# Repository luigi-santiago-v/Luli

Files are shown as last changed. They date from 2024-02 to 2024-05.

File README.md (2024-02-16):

# Luli Hydroponics

## Project Overview
This project aims to create a user-friendly, data-driven, and internet-connected hydroponics system. Targeting food deserts, it offers a solution for accessible nutritious food through a smart home appliance. The system integrates temperature/humidity, light intensity, and water pH sensors, along with UV lighting, a water reservoir, a pump, and a microcontroller into a single appliance. It provides real-time plant health and nutrient data, enhanced by a community-driven web application for sharing insights and tips.

## Key Features

- Comprehensive sensor suite for real-time monitoring
- UV lighting and water management for optimal plant growth
- Community web application for knowledge and tips exchange
  - Python Flask + MongoDB backend
- Designed with food deserts and local community reliance in mind
- **Budget:** $500
- **Duration:** 9 months

## Goals
Develop an open-source hydroponic system to enable community-driven, urban agriculture, addressing the challenge of food deserts and their impact on academic performance. The project focuses on simplifying the hydroponics process for beginners, providing a robust system for easy monitoring and maintenance, and fostering community engagement to sustain interest and success in hydroponic gardening.

## Milestones
- Research, design, and component sourcing
- System assembly and testing
- Creation of a functioning prototype from OSB featuring integrated control and monitoring systems
- Demonstration of prototype efficacy with basic crop growth

## Problem Addressed
Tackles the challenges faced by urban growers, including knowledge barriers and the need for continuous system maintenance. Aims to motivate and support users from construction through to the ongoing cultivation process, making hydroponic gardening accessible and engaging.

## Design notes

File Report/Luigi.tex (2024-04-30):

\documentclass[12pt]{article} % Set font size to 12pt
\usepackage[T1]{fontenc} % For setting T1 encoding instead of OT1, typewriter style quotation marks
\usepackage{graphicx} % For including images
\usepackage{float} % For figure placement
\usepackage{titlesec} % For customizing section titles

\usepackage{tocbibind} % For adding the table of contents to the table of contents
\usepackage[toc,page]{appendix} % For adding appendices
\usepackage{url} % For adding URLs in the bibliography
\usepackage{amsmath} % For IPC 2221 Formula
\usepackage{pdfpages} % To include PDFs
\usepackage{listings} % For code formatting
\usepackage{geometry} % For setting page margins
\geometry{a4paper, margin=1in} % Set page margins to 1 inch
\usepackage{parskip}
\usepackage{siunitx}
\usepackage{subcaption} % For subfigures
\usepackage{pdfpages}

\usepackage{listings} % For code formatting
\lstnewenvironment{pythoncode}[1][]
{
    \lstset{
        language=Python,
        basicstyle=\small\ttfamily,
        keywordstyle=\color{blue},
        stringstyle=\color{orange},
        commentstyle=\color{gray},
        numbers=left,
        numberstyle=\tiny,
        numbersep=5pt,
        showstringspaces=false,
        breaklines=true,
        frame=single,
        captionpos=b,
        #1
    }
}
{} % This empty {} has to be there otherwise there's an error

\usepackage{listings} % For code formatting
\lstnewenvironment{htmlcode}[1][]
{
    \lstset{
        language=HTML,
        basicstyle=\small\ttfamily,
        keywordstyle=\color{blue},
        stringstyle=\color{red}, % Changed to red for HTML attributes
        commentstyle=\color{green}, % Changed to green for HTML comments
        numbers=left,
        numberstyle=\tiny,
        numbersep=5pt,
        showstringspaces=false,
        breaklines=true,
        frame=single,
        captionpos=b,
        #1
    }
}
{} % This empty {} has to be there otherwise there's an error

\begin{document}

\widowpenalty=10000
\clubpenalty=10000

\title{Luli Smart Cultivation:A Socially-Connect IoT Hydroponics Solution}

\begin{titlepage}
    \centering
    \vspace*{\stretch{1}}
    {\Large\bfseries SENIOR DESIGN PROJECT\par}
    \vspace{1.5cm}
    {\Large ECE 186B\par}
    \vspace{1.5cm}
    {\Large\bfseries Luli Smart Cultivation: A Socially-Connect IoT Hydroponics Solution\par}
    \vspace{3cm}
    {\large California State University, Fresno\par}
    {\large Lyles College of Engineering\par}
    {\large Electrical and Computer Engineering Department\par}
    \vspace{2cm}
    {\large Dr. Gregory Kriehn\par}
    {\large Professor Roger Moore\par}
    \vspace{2cm}
    {\large BY\par}
    \vspace{1cm}
    {\large Liam Goss\par}
    {\large Luigi Santiago-Villa\par}
    \vspace{\stretch{2}}
\end{titlepage}

% Table of Contents
\tableofcontents
\newpage

% List of Figures
\listoffigures
\newpage

\begin{abstract}
The issue of scaling global agricultural techniques is an ever-evolving problem as we consider notable concerns, such as renewable energy, global food security, loss of natural habitats, and soil degradation. The Luli Hydroponic System provides an automated IoT solution that leverages the ubiquitous nature of social networks to create a community of horticulturalists supported by a democratized collection of data. Furthermore, the system provides the urban agriculturalist with a user friendly and data rich experience that aims to alleviate the barriers to entry, most notably, the high learning curve and initial investment. To accomplish this task, the project incorporates a Raspberry Pi Pico W to serve as the central processing unit of the system. Although small and limited with onboard memory, the Pico is a cost effective component that specializes in optimized software and generous I/O port interfaces that can leverage cloud computing technology. The hydroponic device is compact and equipped with sensors that gather data critical for healthy plant growth. The design of the hydroponic system discreetly houses four DHT-22 temperature and humidity sensors that give an accurate description of the environment. Furthermore, a light sensor, which is nestled closely to the growing trays, will give the user a real time measurement of the 12V 60 watt grow lights attached to the roof. The project is constructed within a \textdollar 500 budget under a 9 month time frame. 
\end{abstract}

\section*{Overview}
The Luli system is an automated hydroponic setup that employs ebb and flow techniques and integrates IoT-capable components to deliver a user-friendly growing experience. The physical design of the device is compact standing at just 31in with a base measuring 24 x 24 in. The structure is lightweight due to the use of oriented strand board and the roof is supported with 1/4 in PVC pipes. The PVC supports allowed us to discreetly route wires to the array of LED growing lights attached to the roof, as well as the sensors located adjacent to the growing containers. The system takes UV, humidity, temperature, and pH measurements to provide a real time account of the environment in which the plants are growing. An ultrasonic sensor in the reservoir tank, which is located under the growing container, will provide an accurate measurement of the solution level. The data collected will be displayed onto a 2.4in OLED screen attached to the front of the system.

In addition, the user can sign into their Luli Hydroponic account to track the device’s data output through the use of the Luli web portal. The sensors send data to the MangoDB database, and the Flask oriented back-end serves a dynamic front-end to the user. From the HTML based front-end, users can adjust the settings of their device and connect with other users to build a network of urban horticulturalists. Furthermore, users are able to share setting profiles and communicate with one another to create a democratized collection of horticulture techniques. Communications are facilitated through a forum page that gives users a space to share updates on the state of their plants and share images of their progress. The online platform is designed to be engaging and functional, whilst maintaining a user friendly environment. 

\pagebreak

The hydroponic system was developed and constructed over the span of 9 months. The initial project budget was set at \textdollar 500. At the point of completion the budget spent was just under budget \textdollar 426. The goal of the project is to bring attention to the prevalence of the food deserts. By building a community of open-source devices, we believe in time that the device will bring nutritional options to those who live in urban environments where nutritional needs are not always met.

\section {Circuit Design and Testing}

\begin{figure}[H]
  \centering
  
  \caption{Circuit Design}
  \label{fig:Schematic}
\end{figure}

The heart of the circuit is the Raspberry Pi Pico W. This microcontroller is a relatively inexpensive unit that gives the user 40 general-purpose input/output pins. At the bottom left of the schematic we can see the array of 60W growing light LEDs. The LED strips require 12V and 3A to operate correctly. This is far above what the Pico can provide and a 12V AC-to-DC power supply unit was added to the design to provide power to the LED arrays and water pump. The rest of the sensors only require a max of 5V and at the center of Figure \ref{fig:Schematic}, we can see a 12V to 5V buck converter. The buck converter provides the bucked down voltage to the sensors of the hydroponics system such as the DHT-22 humidity and temperature sensor, HCSR04 ultrasonic sensor, LTR-390UV-01 light sensor, and PH-4502C analog pH sensor. 

\subsection{Power Supply Testing}

The system has two voltage requirements that the power supply provides. The Raspberry Pi Pico W and sensors can only handle up to 5V. The water pump and LEDs required a higher voltage of 12V. To provide both voltages from a single outlet, a BMOUO 12V AC-to-DC power supply and DORHEA C120503 12V to 5V DC converter are used. Further more, a FILSHU 10A 250V Power Socket Inlet Switch with a Detachable 3-Prong Power Cord connects the power supply to the 120V wall outlet. As shown in Figure \ref{fig:PSU test Circuit}, the smaller buck converter was attached to the power supply. 

\begin{figure}[H]
  \centering
  
  \caption{Power Supply Test Circuit}
  \label{fig:PSU test Circuit}
\end{figure}

With the components all wired, the power cord was plugged into a power outlet, and the 12V power supply was turned on. A green light on the power supply turned on indicating that the unit has not experienced a short or failure. When we measured the output voltage, we got a reading of 12V. This confirmed the operation of the power supply. The multi-meter was then used on the Buck Converter and a steady measurement of 4.9V was observed. This final measurement showed that the entire power supply circuit was functional and the other components were ready to be powered. 

\subsection{DHT Sensor Testing}

\begin{figure}[H]
  \centering
  
  \caption{DHT-22 Test Circuit}
  \label{fig:DHT-22 Test Circuit}
\end{figure}

The Luli Hydroponic System is a host to 5 seamlessly integrated sensors. Each sensor plays a critical role in successful hydroponics, and after acquisition of the components, their functionality and accuracy was tested. The DHT-11 sensor was chosen due to its dual utility as a humidity and temperature sensor. This reduces the number of GIO pins needed from the Pico microcontroller. According to the datasheet provided by Mouser electronics \cite{ref_dht}, the DHT-11 sensor can measure temperatures within an accuracy of $\pm 2^\circ\text{C}$. Similarly, humidity measurements have an accuracy within $\pm 5 \%$. In order to test functionality, the sensor’s VDD pin is connected to the VBUS of the microcontroller. The sensor’s data prong is linked to the Pico’s GIO 1 pin, in conjunction with a $5 k\Omega$ pull-up resistor. As shown in Figure \ref{fig:DHT-22 Test Circuit}, the test circuit is completed by connecting the sensor and the microcontroller’s ground together. In order to program the microcontroller, the coding IDE Thonny was used and the software was developed in microPython. The test first defines the data pins connected to the DHT-11 sensors. A while loop is used to continuously poll the sensors until a successful measurement is conducted and the output is printed. A short delay of 3 seconds is provided inline with the sensor’s minimum measurement rate.

\begin{figure}[H]
  \centering
  
  \caption{DHT-11 Failed Test}
  \label{fig:DHT-22 Accuracy test}
\end{figure}

The First round of testing on the DHT-11 proved unsuccessful, and as shown in Figure \ref{fig:DHT-22 Accuracy test}, a Timeout error was encountered when attempting to gather measurements. To determine the source of the fault, it was important to test the remaining supply of DHT-11 sensors with the test circuit before any modifications to the code or circuit were made. After swapping each DHT-11 sensor, it was discovered that each behaved in the same manner and the timeout error was not resolved. The timeout error is typically caused when a sensor fails to respond with data within an expected period of time. Therefore, the delay within the test code was reduced to the minimum delay of 1s, which is specified in the DHT-11 datasheet, and then adjusted far longer than needed. Neither change produced a successful result and therefore attention was returned again to the hardware. 

In an attempt to further pinpoint the cause of the issue, it was then assumed that the sensors used could in fact be malfunctioning. To test this theory, an alteration to the test circuit was made by replacing the sensor with its more reliable version, the DHT-22. After swapping the sensors in the test circuit, the code was run in Thonny and an attempt to gather environmental measurements was attempted. The exchange in sensors proved to be successful and a temperature reading was returned. Depicted in Figure \ref{fig:DHT-22 Succesful test}, the DHT-22 sensors returned humidity and temperature data after a series of readings and it was therefore decided to alter the original design of the system to include DHT-22 sensors instead of the DHT-11 sensors. 

\begin{figure}[H]
  \centering
  
  \caption{DHT-22 Successful Readings}
  \label{fig:DHT-22 Succesful test}
\end{figure}

\subsection{OLED Screen}

The screen chosen for our design is the 2.42in OLED LCD display produced by DWEII Electronics. In order to test this screen, we first wired the component to the Raspberry Pi Pico W. The VCC pin on the OLED display was connected to the VBUS of the microcontroller and draws a voltage of 3.3v. When choosing pins on the Raspberry Pi Pico, it was important to note which protocols were supported, and for this test, pins 10-15 were chosen since they support SPI communication. GIO pin 10 was defined as the system clock output and set to a baud rate of 1MHz. The screen communicates with the Pico using SPI communication and the screen acts as the slave unit. To interface the communication between devices pin 11 on the Pico was used as the MOSI port. The reset pin of the screen was connected to GIO pin 14, and pin 13 was connected to the CS pin of the screen. The test circuit was completed by connecting the ground of the screen to the Pico’s ground pin. To drive the circuit, the code, shown in appendix , was written to display a simple “Successful” message to the screen.

\begin{figure}[H]
  \centering
  
  \caption{OLED Display Test Circuit}
  \label{fig:OLED Test}
\end{figure}

The first attempt to drive the screen was unsuccessful. When the code was run, the screen flickered for a brief moment before it turned off and remained black. Since we observed a change in the screen, it was likely that a wire was incorrectly placed or a component was not fully driven into the breadboard. First we ensured that the connections between the components were secured and correct. After checking connections, the board yet again failed to remain on. Next we checked the headers that were soldered onto the OLED screen. Under closer examination, it was discovered that a pin was not fully soldered. The joint had formed a cold joint, and when moved, we observed that there was space between the cold joint and the VCC pin of the screen. Careful attention was given to each header pin to ensure that no other pins were loose, and the headers were re-soldered on with better connections. Once that error was fixed, the program was run, and on the third attempt, the screen turned on and the success message was displayed. Figure \ref{fig:OLED Success} shows the Pico printing the message to the screen and confirms that the unit is functional. 

\begin{figure}[H]
  \centering
  
  \caption{Successful OlED Screen Test}
  \label{fig:OLED Success}
\end{figure}

\subsection{Water Pump}

The water pump chosen for the Luli Hydroponic System was the Gikfun Mini 12v Diaphragm Pump. According to the pump's listing, the unit can take anywhere from 6-12V depending on the speed and power desired from the pump. To test this, the pump was first connected to the output of the 12V power supply. Two water cups were used to provide the pump with a small amount of water from which to draw from. Since the pump will need to pump water up to the grow baskets, the water cups were placed below the pumps to test whether the pump was strong enough to draw water vertically. 

\begin{figure}[H]
  \centering
  
  \caption{Failed Pump Test}
  \label{fig:Pump Fail}
\end{figure}

\pagebreak

When the power was turned on, the pump immediately whirled into operation. Unfortunately, there was a critical error in manner in which the pump was tested. The team did not anticipate the unit moving when turned on. The moment the pump begin to pump water, it twisted due to the rotating components in the pump and fell into one of the cups of water. This caused irreparable damage to the pump. After letting the pump dry over the course of a few days, it was retested and its operation was damaged. The strong flow we initially saw slowed down to a small trickle, and the unit struggled to pull water. In this damaged state the pump would not supply the power necessary to flood three growing trays. Therefore the unit was replaced with a CrocSee 12V DC Diaphragm Pump. During the test of the replacement pump, the pump was taped down to the table to ensure that the same mistake was not repeated. This unit can only be powered with 12V \cite{ref_crocsee} and it was placed into the test circuit. This replacement pump worked exactly as expected and was capable of filling a growing basket. Therefore, the CrocSee diaphragm pump served as our water pumping device for the 3 growing baskets. Vinyl tubing was attached to the intake and outtake ports on the pump. These tubes lead to a cross junction that splits the flow into three vinyl tubes. When the unit was tested with complete vinyl tubing system, it was discovered that the flow of water tended to favor the middle tub. To remedy this issue, the middle tube was replaced with a smaller diameter tube. This corrected the pressure and the three tubes received equal flows of water.   

\subsection{Ultra-Sonic Sensor HC-SR04}

\begin{figure}[H]
  \centering
  
  \caption{Luli Hydroponic System Housing}
  \label{fig:HCSR04 Test Circuit}
\end{figure}

\pagebreak

The HC-SR04 ultrasonic sensor was placed on top of the reservoir tank and takes measurements of the solution’s level. The sensor is accurate within 3mm and has a practical range between 2cm and 80cm \cite{ref_hcsr04}. Two tests were conducted on this sensor. First the unit was tested for functionality. In order to accomplish this, the ultrasonic sensor was interfaced to the Pico by first connecting the VCC pin to the VBUS output of the Raspberry Pi Pico. This provides the unit with the 5V necessary to drive it. The trigger pin was connected to GIO pin 5 and the echo pin was interfaced with GIO pin 6. The microPython program activates the trig pin for 10 microseconds and the echo pin receives the returning ultrasonic pulse, which is transmitted to the Pico for analysis and conversion. Once the data from the ultrasonic pulse is received by the microcontroller, the data must be converted.

\begin{figure}[H]
  \centering
  
  \caption{HRSR04 Accuracy Testing}
  \label{fig:accuracy test}
\end{figure}

In order to confirm that the sensor is reading data correctly, a function was written that first sends a logical 1 value to the trigger pin, and if successful, the transmitter will emit an ultrasonic pulse that the receiver will detect. The echo pin will go high at the end of the transmission and remain high until an ultrasonic pulse is detected by the receiver. Once the function detects the low signal from the echo pin, the difference between the signalOn and signalOff is calculated to determine the period, which is measured in \si{\micro\second}, that the sonic signal took to travel between two points. This time period is then converted by multiplying by the distance sound travels in a micro second:
\begin{equation}
\text{Distance} = \frac{\text{Time Duration} \times 0.0343}{2}
\end{equation}

\begin{figure}[H]
  \centering
  
  \caption{HCSR04 Measurement Results}
  \label{fig:HCSR04 Accuracy Test}
\end{figure}

\pagebreak

When the test code was run, the unit appeared to be operational and a series of measurements were output to the terminal. This confirms that the unit is at least functional, and sends a signal when triggered. In order to test that the data printed was accurate, an object was placed 5.0cm apart from the sensor. A measurement within 3mm would be considered accurate and within the manufacturer specifications \cite{ref_hcsr04}. After running the test code a second time, it was determined that the measurements were sufficiently accurate with a small spike in inaccuracy in the initial rounds of the measurement loop. Overall all the measurements, shown in Figure \ref{fig:HCSR04 Accuracy Test}, were within 3-5mm of the sensor. This is more than acceptable when we consider that the distance of 5.0cm was measured from the front of the receiver’s housing and the actual hardware that detects the echo pulse recedes an unknown distance within the housing. 

\subsection{LED Strips}

\begin{figure}[H]
  \centering
  
  \caption{Arrangment of LEDs}
  \label{fig:LEDarray}
\end{figure}

For growing plants, a set of 60W 12V full spectrum growing LED lights were purchased. Before testing the lights, they were first prepared to be applied to the roof of the enclosure. The LED strips were cut into 12in long strips and 18 gauge wires were soldered on to each to connected them to the power supply. The LED strips have an adhesive back and were attached to the OSB roof panel in the configuration shown in Figure \ref{fig:LEDarray}. A series of eight strips were used with four backup strips applied in case of failure during testing. First a single strip was tested by attaching the LEDs to a power supply device and left on for 10 minutes. Once the functionality of the LEDs was confirmed, the second test was conducted to test the LEDs wired in parallel and the terminal blocks purchased for parallel power supply. 

\begin{figure}[H]
  \centering
  
  \caption{Operation of Growing Lights Compared To Decorative LEDs}
  \label{fig:Comparison}
\end{figure}

After turning on the power supply, no issues were observed. The lights were bright and intense. They gave a soft warmth but did not heat up considerably over the period of 10 minutes. This gave the team confidence that, over a long period, the LEDs will not overheat and loosen the adhesive gluing them to the roof. In Figure \ref{fig:Comparison}, we see a comparison of grow lights to a set of decorative LEDs. In the image, we can see the difference in intensity. With the confirmation of the single strip of LEDs, the final test was conducted on a fully wired array of eight LEDs. The terminal blocks were supplied with 12V and the array immediately lit up. No dead lights were observed, and after a period of ten minutes, it was concluded that the arrays were ready to add to the project. 

\begin{figure}[H]
  \centering
  
  \caption{Successful Parallel Wiring of LED Array}
  \label{fig:Light Array On}
\end{figure}

\section{Physical Enclosure Design and Implementation}

\begin{figure}[H]
  \centering
  
  \caption{Luli Hydroponic System Enclosure Schematic}
  \label{fig: housing schematic}
\end{figure}

The housing of the Luli Hydroponic System is designed to be compact with LEDs and environmental sensors housed in the roof of the enclosure. The body of the system is constructed using an engineered wood material called oriented strand board. This material is often used in large scale constructions for its load bearing properties, due to the lack of internal voids and various orientations of the compressed wood strips. The material is nearly water tight, and the outermost layer requires the application of a water sealant. After cutting the boards to size, three layers of polycrylic sealer were applied to prevent moisture from warping the wood. The housing is split into three individual parts. The design of the bottom enclosure is split into two sections. 

\begin{figure}[H]
  \centering
  
  \caption{Buttom Section with Seperate Compartments}
  \label{fig:bottom compartment}
\end{figure}

The largest of the two sections will hold the reservoir, diaphragm pump, HC-SR04 ultrasonic sensor, and pH pump. The reservoir chosen for this design is the 2 gallon Chaplin International Replacement tank. This tank can hold a substantial amount of fertilizer solutions in a low profile body that is 21.6 x 6 x 8.5in. The reservoir is typically used to mix industrial strength agricultural fertilizers, and this re-purposing would fit within the specifications of its original design. This guarantees that the tank can hold fertilizer materials without degrading due to the pH of the growing solutions. Next to the tank will sit the diaphragm pump with its wires running to the driver board located in the adjoining compartment.

\begin{figure}[H]
  \centering
  
  \caption{Middle Growing Compartement Before Drilling and Adding Growing Trays}
  \label{fig:mid Housing}
\end{figure}

The second compartment of the bottom enclosure is considerably more compact with a width of 6 inches. This is where the core of electronics will be housed. Most notably the power supply and Raspberry Pi Pico W. Special care was taken to ensure that the components would fit. For example, it was discovered that the power supply was too long to fit alongside the breadboard and printed circuit board. In order to save on horizontal space, it was concluded that the unit would need to be installed vertically. With this in consideration, the electronic hardware all fit within this section with the wire control from the various components serving as the final cause of concern.

\begin{figure}[H]
  \centering
  
  \caption{Wiring of The Enclosure with Bulkhead Ports Complete}
  \label{fig:top housing}
\end{figure}

The base was constructed with four 24x10in boards and a 24x24in floor. The OSB does not handle drilling very well and tends to fray when drilled into. Therefore, before any screw was driven into the board, an appropriate pilot hole was drilled. The edges of the boards are too small to drill into. As shown in Figure \ref{fig:bottom compartment}, a series of 2x2in furring strips were used to give the walls a surface to drill the separate panels together. This technique of drilling pilot holes proved to be very successful and no cracks were developed when connecting the sides together. To further ensure that a failure of the plumping or pump would not flood the electronic components, a ring of caulking was applied to the corners of all surfaces. The construction of the base was simple and no complications were encountered. 

\begin{figure}[H]
    \centering
    \begin{subfigure}[b]{0.5\textwidth}
        \centering
        
        \caption{Growing Tubs with 4in Grow Baskets}
        \label{fig:tubGrowbaskets}
    \end{subfigure}
    \begin{subfigure}[b]{0.45\textwidth}
        \centering
        
        \caption{Growing Tubs with Bulkhead Fittings}
        \label{fig:tubBulk}
    \end{subfigure}
    \caption{Growing Tubs}
    \label{fig:renderings}
\end{figure}

Just above the base, is the growing bed that contains the plant trays, base of the PVC roof supports, and ports for plumbing and electric wires. The growing bed was constructed using 5x24in OSB panels and 24x24in OSB floor. Four furring strips were used to give the panels a foundation to which the panels and floor can be attached to make a square growing tray. Once constructed, a series of holes were drilled into the middle compartment. The first of which were the 3/4in holes for routing piping from the bulkheads of the growing trays back to the solution reservoir. The three growing trays themselves are 6Qt 18x5x8in plastic tubs with a 3/4in hole drilled into the bottom. A PVC bulkhead was attached here to allow for draining of the hydroponics solutions. A pair of 4in holes, depicted in Figure \ref{fig:tubGrowbaskets}, were drilled to the top to hold the growing baskets. The baskets along with their piping system were installed with no issue. 

\begin{figure}[H]
  \centering
  
  \caption{Growing Compartment Completed with Wiring, Plumbing, and Roof Support}
  \label{fig:growingCompartment}
\end{figure}

\pagebreak

There are seven external components that require wiring back to the Pico and power supply. The LED array and DHT-22 sensors are placed the furthest and would need 18 gauge wires measuring at least 2-3ft. To freely allow these wires to run from the Raspberry Pi Pico W to the sensors, a 1/2in hole was drilled into the floor of the middle housing section and into the PVC leg cap. The wiring for the roof electronics was carefully feed through the middle compartment port and up the leg cap of the PVC pipe. A steel wire was used to grip the end of the electrical wires and pull it through sections of PVC. The DHT-22 sensors were placed at the corners of the roof and the three wires required for the sensor were pulled to each of the four corners. The power and ground wires were colored coded to a traditional black/red, whilst a blue wire was used to indicate a data line. The power wires for the sensors were attached together with zip ties and the data lines were managed in a similar fashion. A small 3/4in hole was drilled into a horizontal PVC pipe of the roof support to supply the LED array with power. 

\begin{figure}[H]
  \centering
  
  \caption{Completed Enclosure}
  \label{fig:Completed Project}
\end{figure}

\pagebreak

Placing all the electronic components within the enclosure was difficult work that required constant testing after each component was added to the Enclosure. The power supply was first added to the housing, with the 12V DC power supply screwed in vertically to save on space in the circuit section of the bottom enclosure. Furthermore, the PCB and bread board containing the Raspberry Pi Pico W and terminal connections were placed at the forefront of the circuit housing. The wires routed through the PVC pipes were connected to the appropriate terminals on the breadboard. After each collection of sensors were connected, their operations were tested to ensure that they were wired correctly before adding more components. A triangular enclosure was specifically built for the OLED LCD Screen. As shown in Figure \ref{fig:Completed Project} the LCD screen was attached to the front of the Luli System with the use of this enclosure. Before placing the reservoir into the larger compartment of the base, a series of holes were drilled into the top of the reservoir. The pH probe was placed in the deepest portion of the reservoir to ensure constant contact with the solution. The other holes were drilled to place the HCSR04 ultrasonic sensor on top of the tank. With these electronics in place, the reservoir was placed into the housing. The wires from these sensors where connected to the bread board and PCB concluding the housing construction and implementation. 

\section{Front-End Design And Development}

\begin{figure}[H]
  \centering
  
  \caption{Initial Sketch of The Web Portal}
  \label{fig: Portal Sketch}
\end{figure}

\pagebreak

When the Luli Hydroponic system is powered and connected to the internet, the user will interact with the device through the use of the Luli Web Portal. The notable hurdles to horticulturalists new to hydroponics is the high learning curve and constant monitoring of the plants. With this in mind, the design philosophy of the web application places emphasis on user friendly design with a minimalist layout. As shown in Figure \ref{fig: Portal Sketch}, the original sketch of the website gives the user a minimal navigation panel. The user would need to first sign in order to see the real time measurements in the bottom right corner of the sketch. The colors scheme was chosen to give the portal a retro appearance mixed with earthy colors.

\begin{figure}[H]
  \centering
  
  \caption{Create Account Portal}
  \label{fig: create account}
\end{figure}

The front-end was developed using HTML, CSS, and JavaScript, which adds dynamic elements to the static pages. The implementation of the portal is depicted in Figure \ref{fig: create account}, and some key changes were made to the original design. Users now have the option to view their friend's list, post to the cite forum, and adjust their system's settings. Most notably, the measurements were moved from the bottom right corner onto their own separate page. As shown in \ref{fig: plant page}, the plant page is neatly organized with the data presented clear and in a manner that is intuitive. The left panel presents the user with real time measurements served by the Flask supported back-end server. The container left of the measurements is a plant info panel that gives the user information about which plants are currently in the enclosure, important dates, and a field indicating which container holds the plant. 

\begin{figure}[H]
  \centering
  
  \caption{Plant Information Page}
  \label{fig: plant page}
\end{figure}

The settings page gives the user the ability to modify the default settings of their hydroponic system. From settings, the user can choose how often their plants get watered, the amount of water the plants receive, and the duration of the light cycles. Furthermore, users can adjust the plant info panel from this page to better reflect the plants present in their grow trays.

\begin{figure}[H]
  \centering
  
  \caption{Settings Control Panel}
  \label{fig: friends page}
\end{figure}

The social component of the Luli Hydroponic System is demonstrated in Figure \ref{fig: friends page}, where users can give updates about their plant through their about section. The Down arrow is a button where users can download each other settings, which is then applied to their system. Each time the settings page is updated, these friend settings are overwritten. The Luli website establishes a platform where users are able to freely connect, share growing techniques, and building communities with open access to nutritious choices. 

\begin{figure}[H]
  \centering
  
  \caption{Luli Website Friends Page}
  \label{fig: friends page}
\end{figure}

\section{Conclusion}

The Luli Hydroponic System provides a socially connected IoT device that excels in user accessibility. The system contains a network of sensors that give accurate readings of the plant's environment. Additionally, users have access to the Luli web portal where they can connect with other users to form a network of urban horticulturalists. The configuration of the Luli System can be edited from the settings page. From this portal, users can further share their system's settings to create a democratized center of hydroponic data. The system was constructed within a time frame of 9 months and remained well within the budget of \textdollar500. Over the course of this project, the team improved upon valuable skills critical in the engineering field. Through careful time management and task allocation, the project was completed by the projected timeline. The solving of complex problems was facilitated through communicative teamwork. 

\pagebreak

\appendix

\section{Software Appendix}

\begin{pythoncode}[caption={HCSR04 Ultrasonic Sensor Python Test Code}]
import machine
import utime
# Pin assignments
trig = machine.Pin(5, machine.Pin.OUT)
echo = machine.Pin(6, machine.Pin.IN)
def read_distance():
    # Ensure the trigger pin is low for a short time
    timeout = 10000  # timeout in microseconds
    trig.low()
    utime.sleep_us(5)

    # Send a 10us pulse to start the measurement
    trig.high()
    utime.sleep_us(10)
    trig.low()
    # Measure the length of the echo signal
    start_time = utime.ticks_us()
    while echo.value() == 0:
        if (utime.ticks_diff(utime.ticks_us(), start_time) > timeout):
            return None  # return None if no signal detected within the timeout
    signal_off = utime.ticks_us()
    start_time = utime.ticks_us()
    while echo.value() == 1:
        if (utime.ticks_diff(utime.ticks_us(), start_time) > timeout):
            return None  # return None if signal doesn't end within the timeout
    signal_on = utime.ticks_us()
    # Calculate the duration of the echo pulse
    time_passed = utime.ticks_diff(signal_on, signal_off)

    # Calculate distance in centimeters
    distance = (time_passed * 0.0343) / 2
    return distance
while True:
    distance = read_distance()
    if distance is not None and distance > 2:  # Check if distance is plausible
        print("Distance:", distance, "cm")
    else:
        print("Out of range or too close")
    utime.sleep(1)
\end{pythoncode}
\pagebreak
\begin{pythoncode}[caption={DHT-22 Sensor Test Code}]
import dht
from machine import Pin
import machine
import time

print("Starting DHT11.")
d0 = dht.DHT11(machine.Pin(16,Pin.IN,Pin.PULL_DOWN))

while True:
    print("Measuring.")
    
    retry = 0
    while retry < 3:
        try:
            d0.measure()
            break
        except:
            retry = retry + 1
            print(".", end = "")
   
    if retry < 3:
        print("Temperature: %3.1f °C" % d0.temperature())
        print("   Humidity: %3.1f %% RH" % d0.humidity())
    time.sleep(3)

\end{pythoncode}

\pagebreak

\begin{pythoncode}[caption={Main MicroPython Code}]
from machine import Pin, SPI
import ssd1306
import time
spiInit = SPI(1,baudrate=1000000,polarity=1,phase=1,bits=8,firstbit=machine.SPI.MSB,sck=machine.Pin(10),mosi=machine.Pin(11))

cs = Pin(13)   # chip select, some modules do not have a pin for this
dc = Pin(15)    # data/command
rst = Pin(14,Pin.OUT)   # reset

display = ssd1306.SSD1306_SPI(128, 64, spiInit, dc, rst, cs)
dataTest = 123
    
def printSenorData(ph,temp,light,humidity,solution):
    display.fill(0)
    display.hline(7,11,120,1)
    display.fill_rect(0,0,2,64,1)
    #display.text('Environment',6,0,1)
    display.text('pH: '       + str(ph) ,6,16,1)
    display.text('Temp: '     + str(temp),6,27,1)
    display.text('Light: '    + str(light),6,39,1)
    display.text('Humidity: ' + str(humidity),6,51,1)
    display.text('Tank: ' +  str(solution),6,0,1)    
    display.show()

def printPlantMenu():
    display.fill(0)
    display.hline(7,11,120,1)
    display.fill_rect(0,0,2,64,1)
    display.text('Plants',6,0,1)
    display.text('Plant: Spinach',6,16,1)
    display.text('Planted: 5/5/24',6,27,1)
    display.text('Harvest: 9/3/24',6,39,1)
    display.show()
menuSelect = 0;
prevHighlight = 0
display.poweron()
display.show()

while(True):
    printSenorData(dataTest,dataTest,dataTest,dataTest,dataTest)
    time.sleep(6)
    printPlantMenu()
    time.sleep(6)

\end{pythoncode}

\pagebreak
\begin{htmlcode}[caption={Control Panel Html}]

<!-- control_panel.html -->
<!DOCTYPE html>
<html lang="en">
<head>
<meta charset="UTF-8">
<title>Control Panel - LuLi Hydroponics</title>
<link href="{{ url_for('static', filename='style.css') }}" rel="stylesheet">
<script src="{{ url_for('static', filename='scripts/controlPanel.js') }}"></script>
</head>
<body>
<header>
    <img class="logo" src = "{{ url_for('static', filename='images/hydroponic.png')}}" alt = "hydroPlant"  width = 50 height =50 style = "float: left;" >   
    <img src = "{{ url_for('static', filename='images/luli_logo.png')}}" alt="Luli Hydroponics" width = 60 height= 60 style="float: left">
    
</header>
<nav class = "nav_list">
      
    <div class = "button" > 
       <a href="/" target=" _self"><img src = "{{ url_for('static', filename='images/user.png')}}" alt = "login" height= 50 width = 50></a>
       <label class="button_label"> Login </label> 
    </div>
    <div class = "button" > 
       <a href="/plants" target=" _self"> <img src = "{{ url_for('static', filename='images/pot.png')}}" alt = "plant" height= 50 width = 50> </a>
       <label class="button_label"> Plants </label> 
    </div>
    <div class = "button" > 
       <a href="/friends" target=" _self"> <img src = "{{ url_for('static', filename='images/friends.png')}}" alt = "plant" height= 50 width=50> </a>
       <label class="button_label"> Friends </label> 
    </div>
    <div class = "button" > 
       <a href="/forum" target=" _self"> <img src = "{{ url_for('static', filename='images/discussion.png')}}" alt = "plant" height= 50 width=50> </a>
       <label class="button_label"> Forum </label> 
    </div>
    <div class = "button" > 
       <a href="/settings" target=" _self"> <img src = "{{ url_for('static', filename='images/setting.png')}}" alt = "plant" height= 50 width=50> </a>
       <label class="button_label"> Settings </label> 
    </div>
       
   </nav>
<article>
    <div id="controls">
        <button onclick="sendCommand('motor', 'on')">Turn Motor On</button>
        <button onclick="sendCommand('motor', 'off')">Turn Motor Off</button>
        <button onclick="sendCommand('leds', 'on')">Turn LEDs On</button>
        <button onclick="sendCommand('leds', 'off')">Turn LEDs Off</button>
    </div>
</article>
<script>
    function sendCommand(device, action) {
        const data = { [device]: action };
        fetch(`/api/update_manual_override/{{ device_id }}`, {
            method: 'POST',
            headers: { 'Content-Type': 'application/json' },
            body: JSON.stringify(data)
        })
        .then(response => response.json())
        .then(data => console.log('Command sent:', data))
        .catch(error => console.error('Error sending command:', error));
    }
</script>
</body>
</html>
\end{htmlcode}

\pagebreak

\begin{htmlcode}[caption={Create Account HTML}]
<!DOCTYPE html>
<html lang = "en">
<head>
<meta charset = "UTF-8">
<title> LuLi Hydroponics </title>

<link href="style.css" 
      rel = "stylesheet">

</head>

<body>
 
   <header>
      <img class="logo" src = "images/hydroponic.png" alt = "hydroPlant"  width = 50 height =50 style = "float: left;" >   
      <img src = "images/luli_logo.png" alt="Luli Hydroponics" width = 60 height= 60 style="float: left">
      
   </header>

   <nav class = "nav_list">
      
    <div class = "button" > 
       <a href="/" target=" _self"><img src = "images/user.png" alt = "login" height= 50 width = 50></a>
       <label class="button_label"> Login </label> 
    </div>
    <div class = "button" > 
       <a href="/plants" target=" _self"> <img src = "images/pot.png" alt = "plant" height= 50 width = 50> </a>
       <label class="button_label"> Plants </label> 
    </div>
    <div class = "button" > 
       <a href="/friends" target=" _self"> <img src = "images/friends.png" alt = "plant" height= 50 width=50> </a>
       <label class="button_label"> Friends </label> 
    </div>
    <div class = "button" > 
       <a href="/forum" target=" _self"> <img src = "images/discussion.png" alt = "plant" height= 50 width=50> </a>
       <label class="button_label"> Forum </label> 
    </div>
    <div class = "button" > 
       <a href="/settings" target=" _self"> <img src = "images/setting.png" alt = "plant" height= 50 width=50> </a>
       <label class="button_label"> Settings </label> 
    </div>
       
   </nav>
     
<article>
      
      <div id = "createAccount" class="createAccount">
        <div class = "circleLogo">
            <div class = "logoFrontPage">
                <img src = "images/luli_logo.png" alt="Luli Hydroponics" width = 160 height= 160 style="float: center" >
            </div>

        </div>

        <form id="createAccountForm" class = "createAccountForm" action = "/create_account"  method = "POST" enctype="multipart/form-data">

            <div id = "welcomeMessage" class = "welcomeMessage">Welcome to Luli Hydroponics!</div>

            <div class="formGroup">  
               <label for="first-name">First Name:</label>
               <input type="text" id="first-name" name="first-name" required>
            </div>
            <div class="formGroup">
               <label for="last-name">Last Name:</label>
               <input type="text" id="last-name" name="last-name" required>
            </div>
            <div class="formGroup">
               <label for="username">Username:</label>
               <input type="text" id="username" name="username" required>
            </div>
            <div class="formGroup">
               <label for="password">Password:</label>
               <input type="password" id="password" name="password" required>
            </div>
            <div class="formGroup">  
               <label for="profile_pic">Profile Picture:</label>
               <input type="file" id="profile_pic" name="profile_pic" accept="image/jpeg, image/jpg">
            </div>
            <button type="submit" class = "createAccountButton">Create Account</button>
        </form>       

      </div>
</article> 
   
</body>
</html>
\end{htmlcode}

\pagebreak

\begin{htmlcode}[caption={Forum HTML}]
<!DOCTYPE html>
<html lang = "en">
<head>
<meta charset = "UTF-8">
<title> LuLi Hydroponics </title>

<link href="style.css" 
      rel = "stylesheet">

</head>

<body>
 
   <header>
      <img class="logo" src = "images/hydroponic.png" alt = "hydroPlant"  width = 50 height =50 style = "float: left;" >   
      <img src = "images/luli_logo.png" alt="Luli Hydroponics" width = 60 height= 60 style="float: left">
      
   </header>

   <nav class = "nav_list">
      
      <div class = "button" > 
         <a href="/" target=" _self"><img src = "images/user.png" alt = "login" height= 50 width = 50></a>
         <label class="button_label"> Login </label> 
      </div>
      <div class = "button" > 
         <a href="/plants" target=" _self"> <img src = "images/pot.png" alt = "plant" height= 50 width = 50> </a>
         <label class="button_label"> Plants </label> 
      </div>
      <div class = "button" > 
         <a href="/friends" target=" _self"> <img src = "images/friends.png" alt = "plant" height= 50 width=50> </a>
         <label class="button_label"> Friends </label> 
      </div>
      <div class = "button" > 
         <a href="/forum" target=" _self"> <img src = "images/discussion.png" alt = "plant" height= 50 width=50> </a>
         <label class="button_label"> Forum </label> 
      </div>
      <div class = "button" > 
         <a href="/settings" target=" _self"> <img src = "images/setting.png" alt = "plant" height= 50 width=50> </a>
         <label class="button_label"> Settings </label> 
      </div>
         
     </nav>
     
     <article>
      <div id="forumContainer" class="forumContainer">
         <div id="forumPosts" class="forumPosts"> 
            {% for post in posts %}
               <div class="post">
                  <div class="name" style="margin:15px">{{ post.name }}</div>
                  <!-- Check if 'created' exists before using it -->
                  {% if post.get('created') %}
                     <div class="date" style="margin:15px">{{ post.created.strftime('%m/%d/%y %I:%M%p') }}</div>
                  {% else %}
                     <div class="date" style="margin:15px">Date not available</div>
                  {% endif %}
                  <div class="message" style="margin:15px">{{ post.message }}</div>
                  {% if post.image_path %}
                     <img src="{{ url_for('static', filename=post.image_path) }}" alt="Post Image" style="max-width: 500px;">
                  {% endif %}
               </div>
               {% endfor %}
         </div>
         <div id="forumMenu" class="forumMenu">
            <button id="addPostButton">Add Post</button>
         </div>
      </div>
    
      <!-- Modal for Adding a New Post -->
      <div id="postModal" class="modal">
         <div class="modal-content">
             <span class="close">&times;</span>
             <form action="/add_post" method="post" enctype="multipart/form-data">
                 <label for="message">Message:</label>
                 <textarea id="message" name="message" required></textarea><br>
                 <label for="image">Image (optional):</label>
                 <input type="file" id="image" name="image"><br>
                 <button type="submit">Submit</button>
             </form>
         </div>
     </div>
    </article>
    
    <script src="scripts/modal.js"></script>
    
</body>

</html>
\end{htmlcode}

\pagebreak

\begin{htmlcode}[caption={Friends Page HTML}]

<!DOCTYPE html>
<html lang = "en">
<head>
<meta charset = "UTF-8">
<title> LuLi Hydroponics </title>

<link href="{{ url_for('static', filename='style.css') }}" rel="stylesheet">

</head>

<body>
 
   <header>
      <img class="logo" src = "{{ url_for('static', filename='images/hydroponic.png')}}" alt = "hydroPlant"  width = 50 height =50 style = "float: left;" >   
      <img src = "{{ url_for('static', filename='images/luli_logo.png')}}" alt="Luli Hydroponics" width = 60 height= 60 style="float: left">
      
   </header>

   <nav class = "nav_list">
      
      <div class = "button" > 
         <a href="/" target=" _self"><img src = "{{ url_for('static', filename='images/user.png')}}" alt = "login" height= 50 width = 50></a>
         <label class="button_label"> Login </label> 
      </div>
      <div class = "button" > 
         <a href="/plants" target=" _self"> <img src = "{{ url_for('static', filename='images/pot.png')}}" alt = "plant" height= 50 width = 50> </a>
         <label class="button_label"> Plants </label> 
      </div>
      <div class = "button" > 
         <a href="/friends" target=" _self"> <img src = "{{ url_for('static', filename='images/friends.png')}}" alt = "plant" height= 50 width=50> </a>
         <label class="button_label"> Friends </label> 
      </div>
      <div class = "button" > 
         <a href="/forum" target=" _self"> <img src = "{{ url_for('static', filename='images/discussion.png')}}" alt = "plant" height= 50 width=50> </a>
         <label class="button_label"> Forum </label> 
      </div>
      <div class = "button" > 
         <a href="/settings" target=" _self"> <img src = "{{ url_for('static', filename='images/setting.png')}}" alt = "plant" height= 50 width=50> </a>
         <label class="button_label"> Settings </label> 
      </div>
         
     </nav>
     
     <article id="friendList" class="friendList">
      {% for friend in friends %}
      <div class="friendModule">
          <div class="userProfile">
            <img src="{{ url_for('static', filename='PROFILE_PICS/' + friend.username + '.jpg') }}" alt="profile pic" class="profileImage"/>
              <div class="userName">{{ friend.username }}</div>
          </div>
          <div class="userInfo">
              <p class="userAbout">Download my settings to your Luli Hydroponics system!</p>
              <div class="userInteraction">
                  <button type="button" class="downloadSettings" onclick="handleDownloadSettings(this)" data-friend-id="{{ friend.user_id }}">
                      <img src="{{ url_for('static', filename='images/download.png')}}" alt="download" width="80%"/>
                  </button>
              </div>
          </div>
      </div>
      {% endfor %}
  </article>

   <script src="scripts/settingsDownload.js"></script>

</body>
</html>

\end{htmlcode}

\pagebreak

\begin{htmlcode}[caption={Login Page HTML}]

<!DOCTYPE html>
<html lang = "en">
<head>
<meta charset = "UTF-8">
<title> LuLi Hydroponics </title>

<link href="style.css" 
      rel = "stylesheet">

</head>
<script>
   window.onload = function() {
       const params = new URLSearchParams(window.location.search);
       const msg = params.get('msg');
       if (msg) {
           alert(msg);
       }
   };
</script>

<body>
 
   <header>
      <img class="logo" src = "images/hydroponic.png" alt = "hydroPlant"  width = 50 height =50 style = "float: left;" >   
      <img src = "images/luli_logo.png" alt="Luli Hydroponics" width = 60 height= 60 style="float: left">
      
   </header>

     <nav class = "nav_list">
      
      <div class = "button" > 
         <a href="/" target=" _self"><img src = "images/user.png" alt = "login" height= 50 width = 50></a>
         <label class="button_label"> Login </label> 
      </div>
      <div class = "button" > 
         <a href="/plants" target=" _self"> <img src = "images/pot.png" alt = "plant" height= 50 width = 50> </a>
         <label class="button_label"> Plants </label> 
      </div>
      <div class = "button" > 
         <a href="/friends" target=" _self"> <img src = "images/friends.png" alt = "plant" height= 50 width=50> </a>
         <label class="button_label"> Friends </label> 
      </div>
      <div class = "button" > 
         <a href="/forum" target=" _self"> <img src = "images/discussion.png" alt = "plant" height= 50 width=50> </a>
         <label class="button_label"> Forum </label> 
      </div>
      <div class = "button" > 
         <a href="/settings" target=" _self"> <img src = "images/setting.png" alt = "plant" height= 50 width=50> </a>
         <label class="button_label"> Settings </label> 
      </div>
         
     </nav>
     
     <article>
      <form action="/login" method="POST">
      <div class="module_login">
            
            <div>
            <label for="username" class="profile" > Username:</label>
            <input type="text" id="username" name="username" style="margin-bottom: 15px;">
            </div>
            <div>
            <label for="password" class="password" >Password:</label>
            <input type="password" id="password" name="password" style="margin-bottom: 15px;">
            </div>
            <button type="submit">Login</button>
            <a href = "/create_account"> <button type ="button">Create Account</button> </a>
         </form>
      </div>
   </article> 

</body>

</html>

\end{htmlcode}

\pagebreak

\begin{htmlcode}[caption={Plant Page HTML}]
<!DOCTYPE html>
<html lang = "en">
<head>
<meta charset = "UTF-8">
<title> LuLi Hydroponics </title>

<link href="{{ url_for('static', filename='style.css')}}" 
      rel = "stylesheet">

</head>

<body>
 
   <header>
      <img class="logo" src = "{{ url_for('static', filename='images/hydroponic.png')}}" alt = "hydroPlant"  width = 50 height =50 style = "float: left;" >   
      <img src = "{{ url_for('static', filename='images/luli_logo.png')}}" alt="Luli Hydroponics" width = 60 height= 60 style="float: left">
      
   </header>

   <nav class = "nav_list">
      
      <div class = "button" > 
         <a href="/" target=" _self"><img src = "{{ url_for('static', filename='images/user.png')}}" alt = "login" height= 50 width = 50></a>
         <label class="button_label"> Login </label> 
      </div>
      <div class = "button" > 
         <a href="/plants"><img src="{{ url_for('static', filename='images/pot.png')}}" alt="plant" height="50" width="50"></a>
         <label class="button_label"> Plants </label> 
      </div>
      <div class = "button" > 
         <a href="/friends" target=" _self"> <img src = "{{ url_for('static', filename='images/friends.png')}}" alt = "plant" height= 50 width=50> </a>
         <label class="button_label"> Friends </label> 
      </div>
      <div class = "button" > 
         <a href="/forum" target=" _self"> <img src = "{{ url_for('static', filename='images/discussion.png')}}" alt = "plant" height= 50 width=50> </a>
         <label class="button_label"> Forum </label> 
      </div>
      <div class = "button" > 
         <a href="/settings" target=" _self"> <img src = "{{ url_for('static', filename='images/setting.png')}}" alt = "plant" height= 50 width=50> </a>
         <label class="button_label"> Settings </label> 
      </div>
         
     </nav>
     
     <article>
      
     <div class = "measurements">

     <div class = "measurementBar"> 
      
      </div> 

     <div class = "measurementBar"> 
      
      </div> 

     <div class = "measurementBar"> 
      
      </div> 

     <div class = "measurementBar"> 
      
      </div> 

     <div class = "measurementBar"> 
      
      </div> 

     <div class = "type"> {{sensor_data.light}} </div>
     <div class = "type"> {{sensor_data.temp}}</div>
     <div class = "type"> {{sensor_data.humidity}} </div>
     <div class = "type"> {{sensor_data.ph}} </div>
     <div class = "type"> {{sensor_data.tank}} </div>

     <div class = "type"> LIGHT </div>
     <div class = "type"> TEMP </div>
     <div class = "type"> HUMIDITY </div>
     <div class = "type"> pH </div>
     <div class = "type"> TANK </div>

     </div>

    <div class = "plantSection">

     <div class = "plantInfo">

      <div>
         <img src = "{{ url_for('static', filename='images/plants/spinach.jpeg')}}" alt = "spinach" height = 90% width = 90% class = "plantImages">
      </div>
     
      <div> SPINACH</div>

      <div>Container: </div>
      <div> A </div>

      <div>Planted: </div>
      <div>5/25/24 </div>

      <div>Harvest: </div>
      <div>6/7/24 </div>

     </div>

     <div class = "plantInfo">

      <div>
         <img src = "{{ url_for('static', filename='images/plants/kale.jpeg')}}" alt = "Kale" height = 90% width = 90% class = "plantImages">
      </div>
     
      <div> Kale</div>

      <div>Container: </div>
      <div> A </div>

      <div>Planted: </div>
      <div>5/25/24 </div>

      <div>Harvest: </div>
      <div>6/7/24 </div>

     </div>

     <div class = "plantInfo">

      <div>
         <img src = "{{ url_for('static', filename='images/plants/romaine.jpeg')}}" alt = "Lettuce" height = 90% width = 90% class = "plantImages">
      </div>
     
      <div> Lettuce</div>

      <div>Container: </div>
      <div> B </div>

      <div>Planted: </div>
      <div>5/25/24 </div>

      <div>Harvest: </div>
      <div>6/7/24 </div>

     </div>

    </div>
    </article> 

</body>
</html>

\end{htmlcode}

\pagebreak

\begin{htmlcode}[caption={Settings Page HTML}]
<!DOCTYPE html>
<html lang="en">
<head>
<meta charset="UTF-8">

<title>LuLi Hydroponics</title>
<link href="{{ url_for('static', filename='style.css') }}" rel="stylesheet">
<script src="scripts/settingsSlide.js"></script>

</head>
<body>
<header>
    <img class="logo" src="{{ url_for('static', filename='images/hydroponic.png')}}" alt="hydroPlant" width="50" height="50" style="float: left;">
    <img src="{{ url_for('static', filename='images/luli_logo.png')}}" alt="Luli Hydroponics" width="60" height="60" style="float: left;">
    
</header>
<nav class = "nav_list">
      
    <div class = "button" > 
       <a href="/" target=" _self"><img src = "{{ url_for('static', filename='images/user.png')}}" alt = "login" height= 50 width = 50></a>
       <label class="button_label"> Login </label> 
    </div>
    <div class = "button" > 
       <a href="/plants" target=" _self"> <img src = "{{ url_for('static', filename='images/pot.png')}}" alt = "plant" height= 50 width = 50> </a>
       <label class="button_label"> Plants </label> 
    </div>
    <div class = "button" > 
       <a href="/friends" target=" _self"> <img src = "{{ url_for('static', filename='images/friends.png')}}" alt = "plant" height= 50 width=50> </a>
       <label class="button_label"> Friends </label> 
    </div>
    <div class = "button" > 
       <a href="/forum" target=" _self"> <img src = "{{ url_for('static', filename='images/discussion.png')}}" alt = "plant" height= 50 width=50> </a>
       <label class="button_label"> Forum </label> 
    </div>
    <div class = "button" > 
       <a href="/settings" target=" _self"> <img src = "{{ url_for('static', filename='images/setting.png')}}" alt = "plant" height= 50 width=50> </a>
       <label class="button_label"> Settings </label> 
    </div>
       
   </nav>
<article>

    <form id="settingsForm" action="/save_settings" method="POST">
        <div class="settingsContainer">
            
            <label for="water_interval" id="water_intervalLabel">Water plants every <span id="water_intervalValue">{{ settings.get('water_interval', 12) }} hours</span></label>
            <div class="sliderContainer">
                <input type="range" id="water_interval" name="water_interval" min="1" max="24" value="{{ settings.get('water_interval', 12) }}" oninput="document.getElementById('water_intervalValue').textContent = this.value + ' hours'">
            </div>

            <label for="led_duration" id="led_durationLabel">Turn on LEDs for <span id="led_durationValue">{{ settings.led_duration if settings.led_duration else '12' }}</span> hours</label>
            <div class="sliderContainer">
                <input type="range" id="led_duration" name="led_duration" min="1" max="24" value="{{ settings.led_duration if settings.led_duration else '12' }}" oninput="document.getElementById('led_durationValue').textContent = this.value">
            </div>
    
            <label for="pump_duration" id="pump_durationLabel">Water for <span id="pump_durationValue">{{ settings.pump_duration if settings.pump_duration else '5' }}</span> minutes per cycle</label>

            <div class="sliderContainer">
                <input type="range" id="pump_duration" name="pump_duration" min="1" max="15" value="{{ settings.pump_duration if settings.pump_duration else '5' }}" oninput="document.getElementById('pump_durationValue').textContent = this.value">
            </div>
    
            <div class="settingsButton">
                <button type="submit" id="saveSettingsButton">Save Settings</button>
            </div>
        </div>
    </form>
    
    <div class = "plantInfoSettingsContainer">
    
        <div id = "plantAmount" class = "plantAmount" >
            <label for="quantity">Number of Plants:</label>
            <input type="number" id="quantity" name="quantity" min="1" max="6" class = "spinVisible" onchange = "updateSettingsCarousel()">
        </div>

        <div id = "plantCarousel" class = "plantCarousel">
            <div id="indPlantSettings" class = "indPlantSettings" >

                <div>
                    <label for="plantType">Plant Type:</label>
                    <select id="plantType" name="plantType">
                            <option value="Spinach">Spinach</option>
                            <option value="Romaine">Romaine</option>
                            <option value="Basil">Basil</option>
                            <option value="Cilantro">Cilantro</option>
                            <option value="Green Onions">Green Onions</option>
                            <option value="Kale">Kale</option>
                            <option value="Mint">Mint</option>
                            <option value="Oregano">Oregano</option>
                            <option value="Parsley">Parsley</option>
                            <option value="Radish">Radish</option>

                    </select>
                </div>

                <div>
                    <label for="start">Date Planted:</label>
                    <input type="date" id="start" name="trip-start" value="2024-01-01" min="2023-01-01" max="2026-12-31" class="custom-calendar"/>
                </div>
                
                <div>
                    <label for="start">Date of Harvest:</label>
                    <input type="date" id="start" name="trip-start" value="2024-01-01" min="2023-01-01" max="2026-12-31" />
                </div>
            
                <div>
                    <label for="letters">Choose Container:</label>
                    <select id="letters" name="letters">
                            <option value="A">A</option>
                            <option value="B">B</option>
                            <option value="C">C</option>
                    </select>
                </div>
            </div>
        </div>

    </div>

</article>
<script src="scripts/settingsSlide.js"  defer></script>
<script src="scripts/dynamicSettingsCarousel.js"  defer></script>
</body>
</html>

\end{htmlcode}

\pagebreak

\begin{htmlcode}[caption={CSS Stlye Sheet}]

.nav_list
{
    display: flex;
    flex-direction: column;
    justify-content: center;
    align-items: center;
}

.button
{
   display: flex;
   flex-direction: column;
   align-items: center;
   padding: 10px 10px ;
   border: 3px solid black;
   width: 70px; 
   height: 70px; 
   background: rgb(206 249 173);
   box-shadow: 4px 4px 4px black;
   border-radius: 15px 15px;
   margin-top: auto;
}
    
.user 
{
   display: inline-block;
   width: 150px;
   height: 150px;
   border-radius: 15px 15px 15px 15px;
   margin-top: 40px;
   margin-bottom: 60px;
   background-repeat: no-repeat;
   background-position: center center;
   background-size: cover;
   background-image: url('hydroponic.png');
}
    
.profile
{
   margin-right: 04px;
}
    
.password
{
   margin-right: 4px;
}

.createAccount
{
   display:grid;
   grid-template-columns: 40% 60%;
   width: 80%;
   height: 80%;
   background: rgb(206 249 173);
   box-shadow: 4px 4px 4px black;
   border: 4px solid black;
   border-radius: 15px 15px 15px 15px;
   justify-content: center;
   align-items: center;

}

.welcomeMessage
{
   display:flex;
   background-color:rgb(237 176 102); 
   width: 100%;
   height: 25%;
   border-radius: 0px 11px 0px 0px;
   justify-content: center;
   align-items: center;
   margin-top: -41px;
   
}

.createAccountForm
{
   display: flex;
   flex-direction: column;
   gap: 40px;
   height: 100%;
   width: 100%;
   justify-content: center;
   align-items: center;

}

.createAcountButton 
{
width: 100px;
}

.circleLogo
{
   display: flex;
   flex-direction: column;
   background-color: rgb(126 198 204);
   border-radius: 12px 0px 0px 12px;
   width: 100%;
   height: 100%;
   justify-content: center;
   align-items: center;
   gap: 20px;
}

.logoFrontPage
{
   background-color: rgb(132 158 214);
   box-shadow: 4px 4px 4px black;
   border: 4px solid black;
   border-radius: 50%;
   padding: 30px;
}

.module_login
{
   font-size: 23px;
   display: flex;
   gap:15px;
   flex-direction:column;
   align-items: center;
   width: 400px;
   height: 500px;
   background: rgb(206 249 173);
   box-shadow: 4px 4px 4px black;
   border: 4px solid black;
   border-radius: 15px 15px 15px 15px;
}
    
.module_login div 
{
   display: flex;
   flex-direction: row;       
}
    
 .button_label
{
   font-size: 18px;
}
    
.button:hover
{
   background: gainsboro;
   transform: scale(1.05, 1.05);
}
    
body
{
  
   background: rgba(206, 249, 173, 0.578);
   display: grid;
   grid-template-columns: 130px 1fr;
   grid-template-rows:auto 670px;
   grid-template-areas: 
   "header header "
   "nav art ";
   font-size: 2em;
   text-align: center;
   border-radius:15px;
   box-shadow: 4px 4px 4px black;
   min-width: 700px;
   font-family: monospace;
}

header 
{
   grid-area:header;
   background: rgb(126 198 204);
   line-height: 100%;
   border-radius:15px 15px 0px 0px;
   margin-bottom: 2px;
   border: 4px solid black;
}
    
.corner_topRight
{
   background: rgb(206 249 173);
   line-height: 100%;
   width: 10%;
   height: 100%;
   border-left: 4px solid black;
   border-radius: 0px 11px 0px 0px;
   float:right;
}
    
.corner_bottomLeft
{
   background: rgb(206 249 173);
   width:100%;
   height:20%;
   border-top: 4px solid black;
   border-radius: 0px 0px 0px 10px;
   margin-top: auto;       
}
    
nav 
{
   grid-area:nav;
   background: rgb(132 158 214);
   border: 4px solid black;
   border-radius: 0px 0px 0px 15px;
   margin-top: -4px;
   margin-right: -4px;    
}
     
article
{
   grid-area: art;
   display: flex;
   background: rgb(237 176 102);
   border-radius: 0px 0px 15px 0px;
   width: auto;
   border: 4px solid black;
   margin-top: -4px;
   justify-content: center;
   align-items: center;
    
}

.measurements
{
   font-size: 23px;
   display: grid;
   grid-template-columns: 20% 20% 20% 20% 20% ;
   grid-template-rows: 85% 7.5% 7.5%;
   width: 500px;
   height: 500px;
   background: rgb(206 249 173);
   box-shadow: 4px 4px 4px black;
   border: 4px solid black;
   border-radius: 15px 15px 15px 15px;
   place-items: center;
   margin: auto 2% auto 2%

}

.plantSection
{
   font-size: 23px;
   display: flex;
   scroll-snap-type: x mandatory;
   background-color: rgb(206 249 173);
   overflow-x: auto;
   width: 450px;
   height: 500px;
   border-radius: 15px 15px 15px 15px;
   place-items: center;
   max-width: 350;
   position: relative;
   box-shadow: 4px 4px 4px black;
   border: 4px solid black;
   overflow: auto;
}

.plantInfo
{
   font-size: 23px;
   display: grid;
   flex-shrink: 0;
   scroll-snap-align: start;
   scroll-behavior: smooth;
   scroll-snap-type:proximity;
   grid-template-columns: 50% 50% ;
   grid-template-rows: 30% 17.5% 17.5% 17.5% 17.5%;
   width: 450px;
   height: 100%;
   background: rgb(206 249 173);
   place-items: center;
   scroll-snap-align: center;

}

.plantImages
{
margin: 15px auto auto 15px;
border-radius:15px;
height: 50%;
box-shadow: 2px 2px 2px black;
}

/* width */
::-webkit-scrollbar {
   width: 2px;
   height: 20px;
   border-radius: 15px;
 }
 
 /* Track */
 ::-webkit-scrollbar-track {
   background: rgb(132 158 214);
   border: 4px 0px 0px 0px solid black;
   border-radius: 0px 0px 10px 10px  ;
 }
 
 /* Handle */
 ::-webkit-scrollbar-thumb {
   background: rgb(126 198 204);
   border-radius: 15px;
}
 
 /* Handle on hover */
 ::-webkit-scrollbar-thumb:hover {
   background: rgb(237 176 102);
 }

.measurementBar
{
   position: relative;
   height: 380px;
   width : 35px;
   border-radius: 15px 15px 15px 15px;
   border: 4px solid black;
   background: white;
   margin: auto auto auto auto;
}

.barProgress {
   position: absolute; 
   bottom: 0; 
   border-radius: 0px 0px 11px 11px; 
   margin: auto; 
}

.forumContainer
{
   display:grid;
   grid-template-columns: 80% 20%;
   grid-area: 
   "forumPost" "forumMenu" ;
   overflow: auto;
   width: 100%;
   height: 100%;
   place-items: center;
   justify-content: center;
   overflow: auto;
}

.forumPosts
{
   display: flex;
   flex-direction: column;
   gap:15px;
   height: 100%;
   width: 90%;
  
}

.post
{

   width: 100%;
   height: 400px;
   border: 4px solid black;
   box-shadow:  2px 2px 2px black;
   background-color: rgb(132 158 214);
   text-align: left;
}

.forumMenu
{ 
   position: fixed;
   bottom: 100px; /* Adjust as needed */
   right: 40px; /* Adjust as needed */
   display: flex;
   flex-direction: column;
   height: 200px;
   width : 200px;
   justify-content:end;

}

.forumButton
{
   width:40% ;
   height:30%;
   background-color: rgb(206 249 173);
   border-radius: 15px;
   border: 4px solid black;
   box-shadow:  2px 2px 2px black;
}

.forumButton:hover
{
   transform: scale(1.1);
}

.settingsContainer
{
   font-size: 23px;
   display: grid;
   background-color: rgb(132 158 214) ;
   grid-template-columns: 20% 80%;
   grid-template-rows: 25% 25% 25% 25% ;
   grid-area: 
   "waterCycle" "waterCycle"
   "waterAmount" "waterAmount"
   "Lightcycle" "Lightcycle"
   "LightDuration" "LightDuration";
   place-items: center;
   width: 45%;
   height: 80%;
   border-radius: 15px 15px 15px 15px;
   border: 4px solid black;
   box-shadow:  2px 2px 2px black;
   margin: auto;
}

.plantInfoSettingsContainer
{
   font-size: 23px;
   display: grid;
   background-color: rgb(206 249 173) ;
   grid-template-rows: 20% 80%;
   place-items: center;
   width: 30%;
   height: 80%;
   border-radius: 15px 15px 15px 15px;
   border: 4px solid black;
   box-shadow:  2px 2px 2px black;
   margin: auto;
}

.plantAmount
{
   display: flex;
   width: 100%;
   height:100%;
   background-color: rgb(132 158 214);
   border-radius: 12px 12px 0px 0px;
   flex-direction: row;
   gap: 10px;
   place-items: center;
   justify-content: center;
}

.indPlantSettings
{
   display: flex;
   flex-direction: column;
   gap: 15px;
   width:100%;
   height:100%;
   flex-shrink: 0;
   scroll-snap-align: start;
   scroll-behavior: smooth;
   scroll-snap-type:proximity;
   scroll-snap-align: center;
   place-items: center;
   justify-content: center;

}

.plantCarousel
{
   display: flex;
   flex-direction: row;
   height:100%;
   width:100%;
   font-size: 23px;
   scroll-snap-align: start;
   scroll-behavior: smooth;
   scroll-snap-type:proximity;
   scroll-snap-align: center;
   overflow: auto;
   scroll-snap-type: x mandatory;
   
}
.friendList {
   display: flex;
   flex-direction: row;
   scroll-snap-align: start;
   scroll-behavior: smooth;
   scroll-snap-type: x mandatory;
   overflow: auto;
   justify-content:start;
}

.friendModule
{
   font-size: 23px;
   display: grid;
   grid-template-rows: 50% 50%;
   grid-template-columns: 100%;
   width: 500px;
   height: 500px;
   background: rgb(206 249 173);
   box-shadow: 4px 4px 4px black;
   border: 4px solid black;
   border-radius: 15px 15px 15px 15px;
   flex-shrink: 0;
   justify-content: start;
   margin: 10px;
}

.userProfile
{
   display: grid;
   grid-template-columns: 50% 50%;
   justify-content: center;
   align-items: center;
   background-color: rgb(132 158 214);
   width: 100%;
   height: 100%;
   border-radius: 11px 11px 0px 0px;

}

.profileImage
{
      width: 100%;
      height: 80%;
      border-radius: 15px;
      background-color: #ccc;
      background-size: cover;
      background-position: center;
      margin:10px;
      box-shadow: 4px 4px 4px black;
      border: 2px solid black;
}

.userInfo
{
   display:grid;
   grid-template-columns: 80% 20%;
   height: 100%;
   width: 100%;

}

.userAbout
{
   text-align: left;
   margin:10px
}

.userInteraction
{
   background-color: rgb(126 198 204);
   width: 100%;
   height: 100%;
   border-radius: 0px 0px 11px 0px;
}

.downloadSettings{
   background-color: rgb(237 176 102);
   width: 80%;
   height: 30%;
   border-radius: 15px;
   box-shadow: 4px 4px 4px black;
   border: 2px solid black;
   margin: 10px;
   cursor: pointer;
   transition: transform 0.2s; 
}

.downloadSettings:hover {
   transform: scale(1.1);
}

.spinVisible::-webkit-outer-spin-button,
.spinVisible::-webkit-inner-spin-button 
{
    opacity: 1;
}

/* width */
input[type="range"] {
   width: 85%;
   height: 5px;
   -webkit-appearance:none;
   appearance: none;
   border: 3px solid rgb(206 249 173);
   background-color: rgb(206 249 173);
   box-shadow: 3px 3px 3px black;
   /* Add rounded corners */
   border-radius: 20px;
 }

 input[type="range"]::-webkit-slider-thumb 
 {
   width: 20px;
   height: 30px;
   background: rgb(237 176 102);
   border-radius: 25%;
   border: 2px solid black;
   box-shadow: 1px 1px 1px black;
   -webkit-appearance: none;

 }

 .settingsContainer input[type="range"]:active::-webkit-slider-thumb {
   transform: scale(1.3);
}

.settingInput
{
   width: auto;
   height: auto;
   display: flex;
   flex-direction: row;
   gap: 10px;
}

#slideLabel
{
   display:block;
   width: 100%;
   height: 100%;
   background-color: rgb(126 198 204);
   border-radius: 0px 0px 0px 0px;
   align-content: center;
  
   margin-left:auto;
   font-size: 20px;
}

#slideLabelTop
{
   display:block;
   width: 100%;
   height: 100%;
   background-color: rgb(126 198 204);
   border-radius: 12px 0px 0px 0px;
   align-content: center;
   margin-left:auto;
   font-size: 20px;
}
#containerSlideValue
{
  
   display: flex;
   flex-direction: row;
   gap: 15px;
   margin-left: 5px;
}

#slideValue
{
   font-size: 18px;
   margin: auto;
}

#slideLabelBottom
{
   display:block;
   width: 100%;
   height: 100%;
   background-color: rgb(126 198 204);
   border-radius: 0px 0px 0px 12px;
   align-content: center;
   margin-left:auto;
   font-size: 20px;
}

.type
{
   font-size: 20px;
   font-family: monospace;
   margin: auto auto 80% auto;
}

aside 
{
   background: goldenrod;
   line-height: 180px;
}
    
section 
{
   background: lightsteelblue;
   line-height: 90px;
}
    
footer 
{
   background: lemonchiffon;
   line-height: 40px;
}
    
.logo
{
   margin-top: 5px;
   margin-left: 10px;
   margin-right: 10px;
}
    
\end{htmlcode}

\pagebreak

\begin{thebibliography}{99}

    \bibitem{ref_dht} "DHT22 Datasheet," Mouser Electronics. [Online]. Available: \url{https://www.mouser.com/datasheet/2/737/dht-932870.pdf}.

    \bibitem{ref_hcsr04} SparkFun Electronics, "HC-SR04 Ultrasonic Sensor Datasheet," SparkFun Electronics. [Online]. Available: \url{https://cdn.sparkfun.com/datasheets/Sensors/Proximity/HCSR04.pdf}. [Accessed: April 29, 2024].

    \bibitem{ref_ph_amazon} GAOHOU. (n.d.). PH0-14 Value Detect Sensor Module + PH Electrode Probe BNC For Arduino [Online]. Available: \url{https://www.amazon.com/dp/B0799BXMVJ?psc=1&ref=ppx_yo2ov_dt_b_product_details}
    
    \bibitem{ref_ipc_2221} IPC, "IPC-2221C - Generic Standard on Printed Board Design," IPC International, Bannockburn, IL, Standard, Dec. 2023. [Online]. Available: \url{https://shop.ipc.org/2221-STD-0-D-0-EN-C}
    \bibitem{ref_boveda} Boveda. "Boveda Size 60 (4 Pack) 69\% RH for Cigar." Boveda, [online] Available: \url{https://store.bovedainc.com/collections/for-cigars/products/boveda-size-60-4-pack-69-rh-for-cigar} 
    \bibitem{ref_uvforum} T. Tonygo2, "LTR390 Micropython Code," Pimoroni Community Forum, 04-Dec-2021. [Online]. Available: \url{https://forums.pimoroni.com/t/ltr390-micropython-code/22314/2}.
    \bibitem{ref_crocsee} "CrocSee DC 12V Mini Food Grade Self Priming Diaphragm Fresh Water Transfer Pump 1.3LPM, Replacement Pump for Ice Maker, Coffee Machine, Water Dispenser," Amazon. [Online]. Available: \url{https://www.amazon.com/CrocSee-Diaphragm-Transfer-Replacement-Dispenser/dp/B09XH1GYYQ}. 
    \bibitem{ref_gikfun} "Gikfun 12V DC Dosing Pump Peristaltic Dosing Head with Connector for Arduino Aquarium Lab Analytic DIY AE1207," Gikfun Store. [Online]. Available: \url{https://www.amazon.com/Gikfun-Peristaltic-Connector-Aquarium-Analytic/dp/B01IUVHB8E}. 
    \bibitem{ref_growled} "Plant Grow LED Light, OUEVA 16.4ft/5M 5050 SMD Waterproof Full Spectrum Red Blue 5:1 Growing Lamp for Aquarium Greenhouse Hydroponic Plant, Garden Flowers Veg Grow Light," OUEVA Store, [Online]. Available: \url{https://www.amazon.com/Plant-OUEVA-16-4ft-Waterproof-Spectrum/dp/B06XCJG4M6}.
    \bibitem{ref_oldled} "USB Black Light Strip, 6.6ft 10W UV LED Blacklight String Lights, 395-400nm, DC 5V, 120 Lamp Beads, Glow in the Dark for Halloween, Birthday, Party, Fluorescent Poster, Room, Bedroom Decoration," GREENIC Store, [Online]. Available: \url{https://www.amazon.com/Blacklight-395-400nm-Halloween-Fluorescent-Decoration/dp/B0B99L22B8}.
    \bibitem{ref_ltr390} Lite-On Inc., "LTR-390UV Final Datasheet." [Online]. Available: \url{https://optoelectronics.liteon.com/upload/download/DS86-2015-0004/LTR-390UV_Final_%20DS_V1%201.pdf}.
    \bibitem{ref_mosfet} Infineon Technologies AG, "IRLZ34NPBF Datasheet." [Online]. Available: \url{https://www.infineon.com/dgdl/irlz34npbf.pdf?fileId=5546d462533600a40153567206892720}.
    \bibitem{ref_capacitor} Rubycon Corporation, "ZLH Series Aluminum Electrolytic Capacitors." [Online]. Available: \url{https://www.rubycon.co.jp/wp-content/uploads/catalog-aluminum/ZLH.pdf}.
    \bibitem{ref_diode} ON Semiconductor, "1N4001, 1N4002, 1N4003, 1N4004, 1N4005, 1N4006, 1N4007 Axial-Lead Glass Passivated Standard Recovery Rectifiers Datasheet." [Online]. Available: \url{https://www.onsemi.com/pdf/datasheet/1n4001-d.pdf}.
    \bibitem{ref_phsensor} "PH Sensor PH-4502C Datasheet." [Online]. Available: \url{https://cdn.awsli.com.br/969/969921/arquivos/ph-sensor-ph-4502c.pdf}.
    \bibitem{ref_pico_w} Raspberry Pi Foundation, "Raspberry Pi Pico W Datasheet." [Online]. Available: \url{https://datasheets.raspberrypi.com/picow/pico-w-datasheet.pdf}.
    \bibitem{ref_mux} Texas Instruments, "SN54S151 Data Selector/Multiplexer Datasheet." [Online]. Available: \url{https://www.ti.com/lit/ds/symlink/sn54s151.pdf?ts=1714290231547}.

    % Repeat for each reference
\end{thebibliography}

\end{document}

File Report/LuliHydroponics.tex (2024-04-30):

\documentclass[12pt]{article} % Set font size to 12pt
\usepackage[T1]{fontenc} % For setting T1 encoding instead of OT1, typewriter style quotation marks
\usepackage{graphicx} % For including images
\usepackage{float} % For figure placement
\usepackage{titlesec} % For customizing section titles
\usepackage{lipsum} % For generating dummy text during development
\usepackage{tocbibind} % For adding the table of contents to the table of contents
\usepackage[toc,page]{appendix} % For adding appendices
\usepackage{url} % For adding URLs in the bibliography
\usepackage{amsmath} % For IPC 2221 Formula
\usepackage{pdfpages} % To include PDFs
\usepackage{listings} % For code formatting
\usepackage{geometry} % For setting page margins
\usepackage{subcaption} % For subfigures
\geometry{a4paper, margin=1in} % Set page margins to 1 inch
% Force fonts to be embedded in PDF file
\usepackage{microtype} % Improve font rendering
\pdfminorversion=7
\pdfcompresslevel=9
\pdfobjcompresslevel=2

\lstnewenvironment{pythoncode}[1][]
{
    \lstset{
        language=Python,
        basicstyle=\small\ttfamily,
        keywordstyle=\color{blue},
        stringstyle=\color{orange},
        commentstyle=\color{gray},
        numbers=left,
        numberstyle=\tiny,
        numbersep=5pt,
        showstringspaces=false,
        breaklines=true,
        frame=single,
        captionpos=b,
        #1
    }
}
{} % This empty {} has to be there otherwise there's an error
\lstnewenvironment{htmlcode}[1][]
{
    \lstset{
        language=HTML,
        basicstyle=\small\ttfamily,
        keywordstyle=\color{blue},
        stringstyle=\color{red}, % Changed to red for HTML attributes
        commentstyle=\color{green}, % Changed to green for HTML comments
        numbers=left,
        numberstyle=\tiny,
        numbersep=5pt,
        showstringspaces=false,
        breaklines=true,
        frame=single,
        captionpos=b,
        #1
    }
}
{}

\newcommand{\comment}[1]{} % Create a custom comment command
\begin{document}

% Cover Page
\begin{titlepage}
    \centering
    \vspace*{\stretch{1}}
    {\Large\bfseries SENIOR DESIGN PROJECT\par}
    \vspace{1.5cm}
    {\Large ECE 186B\par}
    \vspace{1.5cm}
    {\Large\bfseries LuLi Smart Cultivation: A Socially-Connected IoT Hydroponics Solution\par}
    \vspace{2cm}
    {\large California State University, Fresno\par}
    {\large Lyles College of Engineering\par}
    {\large Electrical and Computer Engineering Department\par}
    \vspace{2cm}
    {\large Dr. Gregory Kriehn\par}
    {\large Professor Roger Moore\par}
    \vspace{2cm}
    {\large BY\par}
    \vspace{1cm}
    {\large Liam Goss\par}
    {\large Luigi Santiago-Villa\par}
    \vspace{2cm} % You may adjust this space to fit your layout needs
    \begin{tabular}{p{0.3\textwidth} p{0.7\textwidth}}
        \textbf{Instructor:} & \hrulefill \\
        & \small Name \hfill Signature \hfill Date \\
    \end{tabular}
    \newline
    \vspace{1cm} % Space between entries
    \begin{tabular}{p{0.3\textwidth} p{0.7\textwidth}}
        \textbf{Technical Advisor:} & \hrulefill \\
        & \small Name \hfill Signature \hfill Date \\
    \end{tabular}
    \vspace{\stretch{2}}
\end{titlepage}
\pagebreak
% Table of Contents
\tableofcontents
\pagebreak

% List of Tables
\listoftables
\pagebreak

% List of Figures
\listoffigures
\pagebreak

% Abstract
\section*{Abstract}
\addcontentsline{toc}{section}{Abstract}
\noindent This project addresses food deserts by developing an accessible, internet-connected hydroponics system, enabling urban households to grow nutritious food. Leveraging temperature, humidity, light intensity, and water pH sensors, alongside UV lighting and a microcontroller, the system facilitates real-time plant health monitoring. A unique feature is its community-driven web application, allowing users to exchange growing tips and presets, significantly lowering the entry barrier for novices. Designed with a focus on food desert challenges and community engagement, the project aims to make home-grown crops viable for everyone. Over nine months and with a \$500 budget, this initiative will produce a functional prototype that demonstrates efficient crop cultivation, highlighting a technology-driven, socially inclusive approach to mitigate food insecurity in urban areas.

% Overview
\section*{Overview}
\addcontentsline{toc}{section}{Overview}
\noindent The hydroponics system has been successfully developed centered around user-friendliness, comprehensive data analytics, and internet connectivity. Functioning seamlessly as a household appliance, the initiative effectively addresses the crucial need for access to nutritious food in areas identified as food deserts. The automated system comprises multiple sensors for monitoring temperature, humidity, light intensity, and water pH, alongside a UV lighting system, water reservoir, water pump, and a microcontroller. These integrated components provide end-users with real-time insights into plant health and nutrient metrics.
\newline
\newline
\noindent Additionally, a web application has been developed to facilitate user interaction, enabling the sharing of insights, posing queries, and exchanging settings presets. Serving as the central nexus for accessing sensor data and engaging with community-driven inputs, this platform significantly enhances user experience. Notably, the solution stands out from existing market offerings because of its meticulous design tailored to address the unique challenges of food deserts and foster reliance on local communities through social networking.
\newline
\newline
\noindent The project, spanning two college semesters and totaling nine months, adhered to a budget allocation of approximately \$500. Major milestones were achieved through meticulous planning and execution, encompassing design and implementation phases, further subdivided into research, component sourcing, component testing, and final integration. The resulting fully functional prototype, constructed from Oriented Strand Board (OSB), incorporates the aforementioned sensors, a microcontroller, lighting apparatus, and water management controls. The completion of a fully operational prototype was accomplished early in the project timeline, allowing for the cultivation of basic crops to vividly demonstrate the efficacy and functionality of the design.

\comment{

% Dedication (Optional)
\section*{Dedication}
\addcontentsline{toc}{section}{Dedication}
\lipsum[1] % Replace with your dedication text

}

\comment {

% Acknowledgment (Optional)
\section*{Acknowledgment}
\addcontentsline{toc}{section}{Acknowledgment}
\lipsum[1] % Replace with your acknowledgment text

}

% Narrative Sections (Example structure)
\pagebreak
\section{Design, Methodology, and Implementation}
\noindent The hydroponics system was designed to address the challenges of food deserts by providing urban households with a sustainable and accessible means of growing fresh produce. The system's design methodology focused on integrating IoT capabilities, real-time monitoring, and community engagement features to enhance user experience and foster a sense of community among users. The implementation process involved sourcing components, designing the circuit, testing individual components, and integrating them into a functional system. The resulting hydroponics system comprises multiple sensors, a microcontroller, a water pump, and a UV lighting system, all working together to create an automated growing environment. The system's web application serves as a central hub for users to monitor plant health metrics, share insights, and exchange growing tips, enhancing the overall user experience. The project's successful completion demonstrates the feasibility of using technology to address food insecurity in urban areas and promote community-driven solutions to social challenges.

\subsection{Circuit Design}
\noindent

\begin{figure}[H]
    \centering
    
    \caption{Circuit Schematic Overview}
    \label{fig:Schematic_Full}
\end{figure}

\noindent The hydroponics system's circuit design was specially crafted to ensure the seamless integration of its diverse components. These include multiple sensors, a microcontroller, a water pump, and a UV lighting system, each fulfilling a distinct role within the automated hydroponic framework. The design facilitates real-time monitoring of environmental conditions, nutrient levels, and plant health metrics, empowering users to optimize growth conditions and ensure robust crop development.
\newline
\newline

\pagebreak\noindent Comprehensive sensor integration encompasses temperature, humidity, light intensity, and water pH, enabling thorough data collection crucial for plant growth assessment. The microcontroller acts as the system's core, gathering sensor data, managing component operations, and supporting user interaction through a web interface. Essential components like the water pump and UV lighting system play vital roles in sustaining optimal growth conditions by ensuring adequate hydration and nutrient distribution.
\newline
\newline
\noindent The circuit design was meticulously planned to accommodate diverse power demands, establish effective communication protocols between sensors and the microcontroller, and enable seamless data exchange for real-time monitoring and control. This systematic approach resulted in a fully operational automated growing environment. The resulting circuit configuration forms a sturdy foundation for monitoring and managing key parameters essential for successful plant cultivation, allowing users to foster healthy crops with minimal manual intervention.
\begin{figure}[H]
    \centering
    
    \caption{Circuit Schematic Designed with Terminal Blocks}
    \label{fig:Schem_TerminalBlocks}
\end{figure}
\noindent In the final month of the project's development, a PCB was designed to house the system's components, providing a compact and organized layout that enhances reliability and ease of maintenance. In order to connect the sensors placed at various distances around the housing, terminal blocks were used to extend the connections. The KiCad PCB designer required that the schematic include these screw terminals to ensure that all nets and wires were connected correctly. The updated schematic (\ref{fig:Schem_TerminalBlocks}) was then used to generate the Gerber files for manufacturing the PCB.

\pagebreak
\subsection{Component Selection}
\noindent 1. \textbf{Microcontroller}
\begin{itemize}
    \item Raspberry Pi Pico W
\end{itemize}

\noindent 2. \textbf{Water Pump}
\begin{itemize}
    \item CrocSee 12VDC Diaphragm Pump
\end{itemize}

\noindent 3. \textbf{Power Supply Unit (PSU)} 
\begin{itemize}
    \item BMOUO 12V AC-to-DC Power Supply 
    \item FILSHU 10A 250V Power Socket Inlet Switch
\end{itemize}

\noindent 4. \textbf{Buck Converter}
\begin{itemize}
    \item DORHEA C120503 12V to 5V DC Converter
\end{itemize}

\noindent 5. \textbf{Sensors}
   \begin{itemize}
   \item Four DHT22 Sensors
   \item LTR-390UV-01 Light Sensor
   \item HC-SR04 ultrasonic sensor
   \item PH-4502C analog pH sensor
   \end{itemize}

\noindent 6. \textbf{Additional Circuit Parts}
   \begin{itemize}
   \item Flyback diode (1N4001RLGOSCT-ND)
   \item 220µF Capacitor (16ZLH220MEFCT16.3X11)
   \item Two N-Channel MOSFET (IRLZ34NPBF-ND)
   \item 8:1 MUX (SN74LS151N)
   \item 2.42" SSD1309 OLED display
   \item 60W full spectrum grow lights
   \item 18 AWG wire
   \item 22 AWG wire
   \end{itemize}

\subsection{Circuit Power Supply Design}
\noindent A 12V30A power supply unit (PSU) was selected to provide the necessary power for the hydroponics system. The PSU was chosen for its high current capacity, ensuring that all system components receive adequate power for optimal performance. The PSU is connected to a FILSHU 10A 250V power socket inlet switch, allowing for easy power management and control. The power supply unit is responsible for delivering the required voltage and current to the system's components, ensuring reliable operation and consistent performance. The PSU's high current capacity enables it to power multiple devices simultaneously, supporting the system's diverse functionalities and ensuring robust operation under varying load conditions.
\newline
\newline
\noindent Connected to the PSU is a DORHEA C120503 12V to 5V DC converter, which steps down the voltage to 5V for powering the Raspberry Pi Pico W microcontroller and various 5V sensors. The DC converter is essential for providing the microcontroller with the appropriate voltage level, ensuring stable operation and preventing damage due to overvoltage. The converter's efficient design and reliable performance make it an ideal choice for powering the microcontroller, enabling seamless integration into the hydroponics system. By converting the 12V input voltage to 5V, the DC converter ensures compatibility with the microcontroller's operating specifications, facilitating reliable communication and control of the system's components.
\newline
\newline
\noindent The inclusion of a 220uF capacitor \cite{ref_capacitor} in the circuit plays a critical role in maintaining the stability and integrity of the power supply, particularly given the dynamic nature of the loads present. This capacitor acts primarily as a decoupling device, providing voltage smoothing to mitigate fluctuations attributable to transient changes in the load, such as those occurring during the activation or deactivation of the motor, or the variable current demands of the LED array. It serves to absorb and release electrical energy, thereby ensuring a consistent voltage supply despite abrupt variations. Furthermore, the capacitor contributes to noise reduction by filtering out electrical interference generated by the motor and the pulsating operation of the LEDs, preserving other sensitive components from potential disruptions. Notably, the buck converter, which is susceptible to input voltage irregularities, benefits from the presence of the capacitor that acts as a buffer against voltage spikes. Moreover, the capacitor enhances the power supply's transient response, promptly supplying current during sudden demand surges, allowing the power supply to adapt effectively to the changing load requirements. This preventive measure ensures both the longevity and performance of the circuit components are optimized, and the risk of malfunctions is minimized.

\pagebreak
\subsection{LED Control Circuit}
\noindent In the development of the LED control system, a low-side switching configuration was implemented using the IRLZ34N N-channel MOSFET. This configuration effectively allows the modulation of a 12V LED strip via signals originating from a Raspberry Pi Pico W microcontroller. The circuit is designed such that the source terminal of the IRLZ34N MOSFET is connected directly to the ground. The drain terminal is connected to the ground terminal of the LED strip, facilitating the control of the negative power line of the strip. The gate terminal of the MOSFET is interfaced with GPIO22 on the Raspberry Pi Pico W, enabling digital control of the LED strip’s operational state. The positive terminal of the LED strip is connected to a 12V power supply, ensuring the provision of the necessary driving voltage for the LEDs.
\newline
\newline
\noindent The IRLZ34N MOSFET \cite{ref_mosfet} operates based on the principles of semiconductor physics concerning the movement of electrons and the manipulation of charge carriers within the device. As an N-channel MOSFET, the primary charge carriers are electrons, which are more mobile than holes. The MOSFET is constructed with a channel between the source and the drain, made of N-type semiconductor material. When a positive voltage is applied to the gate relative to the source, it creates an electric field that induces a conduction channel in the underlying silicon structure. This channel allows electrons to flow from the source to the drain when the gate voltage exceeds a certain threshold, thereby completing the circuit and allowing current to flow through the LED strip.
\newline
\newline
\noindent The effectiveness of this setup is derived from the MOSFET's ability to act as a switch controlled by the gate voltage. With no voltage on the gate, the channel remains non-conductive; hence, the circuit is open and no current flows through the LED strip. Application of a sufficient voltage (approximately 3.3V from the Pico W GPIO) to the gate allows for the formation of the conductive channel, thus closing the circuit and enabling current flow.
\newline
\newline
\noindent The circuit's functionality was verified through a series of tests where the GPIO22 output was alternated between high and low states, corresponding to turning the LED strip on and off, respectively. These tests confirmed that the circuit performed as expected, with the MOSFET effectively controlling the connection between the LED strip and ground based on the GPIO signal. During testing, it was observed that the immediate activation of the LEDs upon application of the 12V supply was mitigated by ensuring correct MOSFET wiring and operation as described. Measurements of voltage levels at the gate, source, and drain were consistent with theoretical expectations, affirming the accuracy of the circuit design and the reliability of the components used.
\newline
\newline
\noindent The implemented design effectively demonstrates the utility of using an N-channel MOSFET for controlling high-power devices like LED strips with low-voltage digital signals from microcontrollers. This configuration not only provides efficient switching capabilities but also simplifies the interfacing between high and low-voltage systems in embedded applications. Further optimization of the circuit could involve the integration of additional control features such as dimming and flashing, which could be achieved by implementing PWM (Pulse Width Modulation) techniques through the Raspberry Pi Pico W.

\subsection{Motor Control Circuit}
\noindent The motor control circuit is similar to the LED control circuit, with the primary difference being the use of a CrocSee 12VDC diaphragm pump as the load. The CrocSee pump is a high-quality diaphragm pump designed for hydroponic systems, aquariums, and other applications requiring water circulation. The pump operates on a 12V DC power supply and is controlled by a Raspberry Pi Pico W microcontroller through an IRLZ34N N-channel MOSFET. The circuit configuration is based on a low-side switching design, allowing the microcontroller to modulate the pump's operational state by controlling the negative power line.
\newline
\newline
\noindent A 1N4001RLGOSCT diode \cite{ref_diode} is used in this circuit as a flyback diode to protect the MOSFET from voltage spikes generated by the pump's inductive load. The flyback diode is reverse-biased during normal operation, allowing current to flow through the pump. When the pump is turned off, the diode becomes forward-biased, providing a path for the voltage spike to dissipate harmlessly.
\newline
\newline
\noindent This circuit is controlled via GPIO21 on the Raspberry Pi Pico W, which is connected to the gate terminal of the IRLZ34N MOSFET. The source terminal of the MOSFET is connected to ground, while the drain terminal is connected to the ground terminal of the CrocSee pump. The positive terminal of the pump is connected to the 12V power supply, ensuring the necessary driving voltage for the pump's operation. By modulating the GPIO21 output between high and low states, the microcontroller can control the pump's operational state, enabling water circulation within the hydroponic system. 
\newline
\newline
\noindent Some pumps can change direction by reversing the polarity of the power supply, but the CrocSee pump used in this circuit operates in a single direction. The pump's operational state can be controlled by turning it on and off as needed to maintain optimal water circulation within the hydroponic system. The circuit's functionality was verified through a series of tests, confirming that the pump could be controlled effectively using the Raspberry Pi Pico W microcontroller. The flyback diode successfully protected the MOSFET from voltage spikes generated by the pump's inductive load, ensuring the circuit's reliability and longevity.
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

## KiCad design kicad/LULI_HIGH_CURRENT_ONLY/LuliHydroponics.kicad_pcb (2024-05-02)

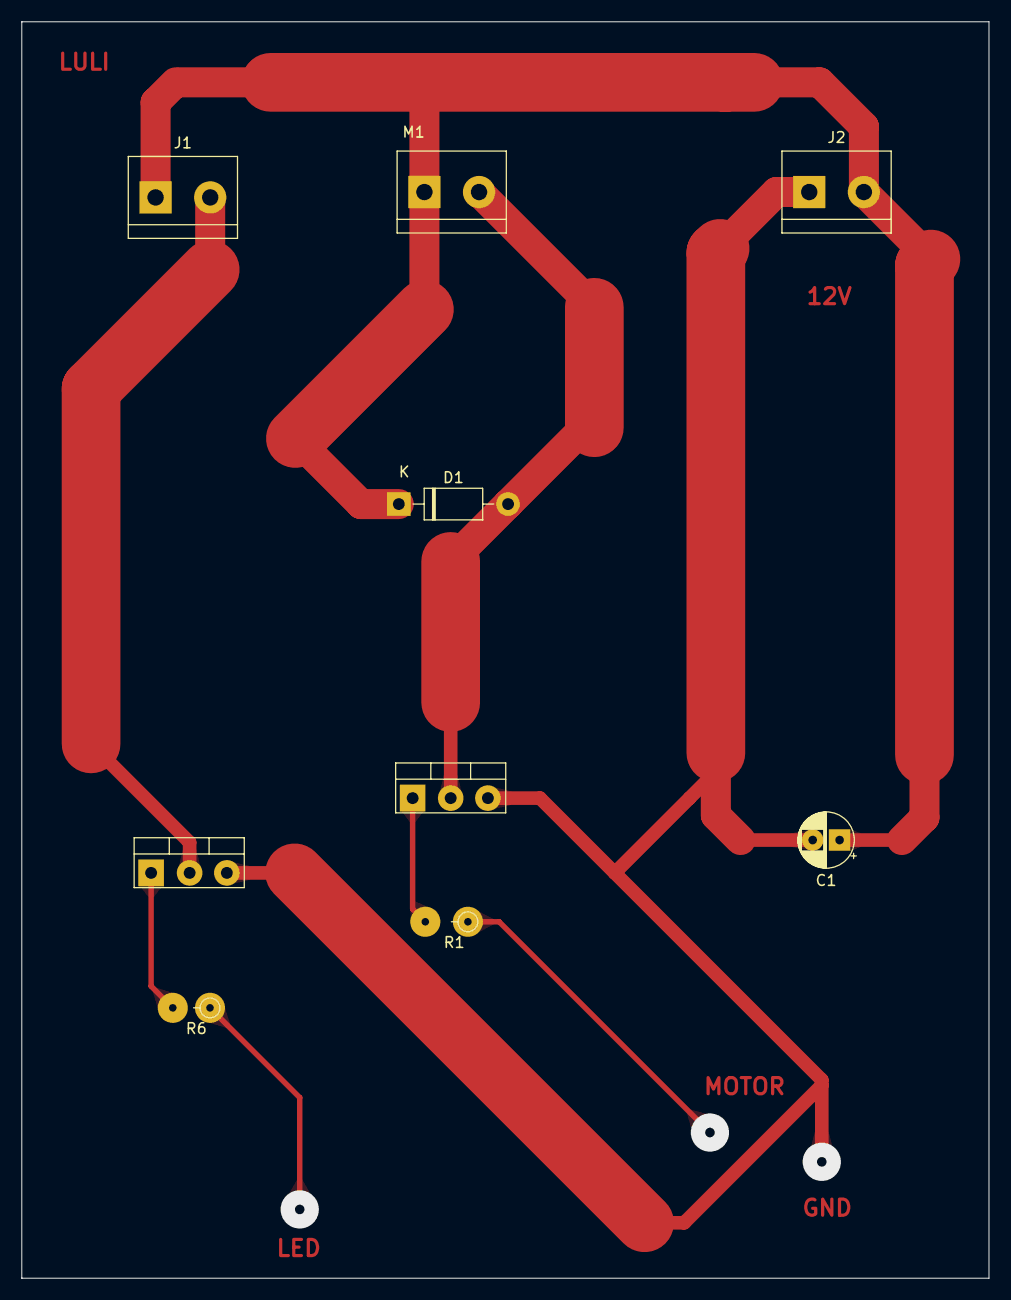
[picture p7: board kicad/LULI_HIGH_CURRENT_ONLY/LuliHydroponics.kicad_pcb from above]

Board: 2 copper layers, 89.9 x 116.9 mm, 9 parts (0 on the bottom side), 6 nets.

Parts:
C1: 220µF; CP_Radial_D5.0mm_P2.50mm
D1: 1N4001; D_DO-41_SOD81_P10.16mm_Horizontal
J1, J2: Screw_Terminal_01x02; TerminalBlock_bornier-2_P5.08mm
M1: Motor_DC; TerminalBlock_bornier-2_P5.08mm
Q1, Q2: IRLZ34N; TO-220-3_Vertical
R1, R6: 1.0kΩ; R_Axial_DIN0204_L3.6mm_D1.6mm_P2.54mm_Vertical

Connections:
GND: C1.2, J2.1, Q1.3 (S), Q2.3 (S)
unnamed: D1.2 (A), M1.2 (-), Q1.2 (D)
unnamed: J1.2, Q2.2 (D)
unnamed: Q1.1 (G), R1.2
unnamed: Q2.1 (G), R6.2
VCC: C1.1, D1.1 (K), J1.1, J2.2, M1.1 (+)

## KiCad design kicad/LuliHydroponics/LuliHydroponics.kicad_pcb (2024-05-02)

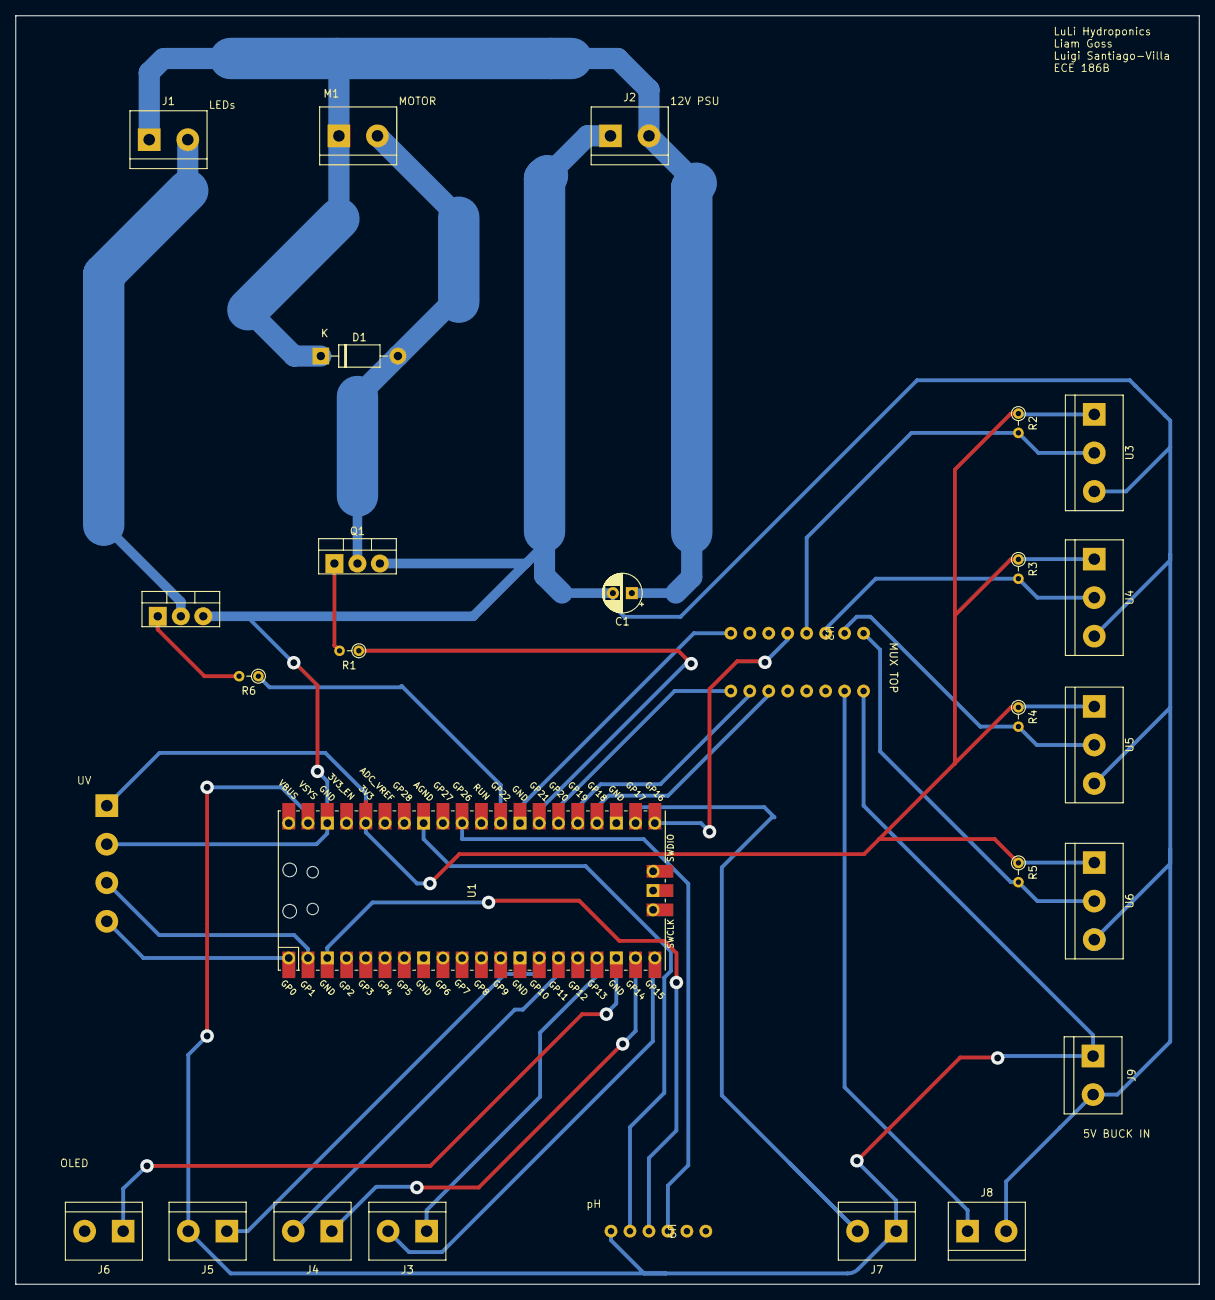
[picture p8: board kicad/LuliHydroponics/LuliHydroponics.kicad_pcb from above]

Board: 2 copper layers, 156.0 x 167.2 mm, 28 parts (1 on the bottom side), 32 nets.

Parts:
C1: 220µF; CP_Radial_D5.0mm_P2.50mm
D1: 1N4001; D_DO-41_SOD81_P10.16mm_Horizontal
J1, J2, J3, J4, J5, J6, J7, J8, J9: Screw_Terminal_01x02; TerminalBlock_bornier-2_P5.08mm
J10: Screw_Terminal_01x05; TerminalBlock_bornier-4_P5.08mm
M1: Motor_DC; TerminalBlock_bornier-2_P5.08mm
Q1, Q2: IRLZ34N; TO-220-3_Vertical
R1, R6: 1.0kΩ; R_Axial_DIN0204_L3.6mm_D1.6mm_P2.54mm_Vertical
R2, R3, R4, R5: 4.7kΩ; R_Axial_DIN0204_L3.6mm_D1.6mm_P2.54mm_Vertical
U1: Pico; RPi_Pico_SMD_TH
U2: 74LS151
U3, U4, U5, U6: DHT11; TerminalBlock_bornier-3_P5.08mm
U9: PH4502C_Footprint

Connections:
/3V3: J10.1, R2.1, R3.1, R4.1, R5.1, U1.36 (3V3), U3.1 (VDD), U4.1 (VDD), U5.1 (VDD), U6.1 (VDD)
/5V: J5.2, J7.1, J9.1, U1.39 (VSYS), U2.16 (VCC), U9.6 (Vin)
GND: C1.2, J2.1, J8.2, J9.2, J10.2, Q1.3 (S), Q2.3 (S), U1.38 (GND), U3.3 (GND), U4.3 (GND), U5.3 (GND), U6.3 (GND)
unnamed: D1.2 (A), M1.2 (-), Q1.2 (D)
unnamed: J1.2, Q2.2 (D)
unnamed: J3.1, U1.17 (GPIO13)
unnamed: J3.2, U1.20 (GPIO15)
unnamed: J4.1, U1.19 (GPIO14)
unnamed: J4.2, U1.15 (GPIO11)
unnamed: J5.1, U1.14 (GPIO10)
unnamed: J6.1, U1.18 (GND)
unnamed: J7.2, U1.22 (GPIO17)
unnamed: J8.1, U2.15 (I4)
unnamed: J10.3, U1.2 (GPIO1)
unnamed: J10.4, U1.1 (GPIO0)
unnamed: Q1.1 (G), R1.2
unnamed: Q2.1 (G), R6.2
unnamed: U1.33 (AGND), U9.5 (GND)
unnamed: U1.3 (GND), U9.4 (GND)
unnamed: U1.21 (GPIO16), U2.5 (Z)
unnamed: U1.24 (GPIO18), U2.11 (S0)
unnamed: U1.25 (GPIO19), U2.10 (S1)
unnamed: U1.26 (GPIO20), U2.9 (S2)
unnamed: R1.1, U1.27 (GPIO21)
unnamed: R6.1, U1.29 (GPIO22)
unnamed: U1.31 (GPIO26_ADC0), U9.3 (Po)
unnamed: U1.28 (GND), U2.8 (GND)
unnamed: R2.2, U2.4 (I0), U3.2 (DATA)
unnamed: R3.2, U2.3 (I1), U4.2 (DATA)
unnamed: R4.2, U2.2 (I2), U5.2 (DATA)
unnamed: R5.2, U2.1 (I3), U6.2 (DATA)
VCC: C1.1, D1.1 (K), J1.1, J2.2, M1.1 (+)

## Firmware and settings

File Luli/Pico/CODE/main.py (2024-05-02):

from Luli_UV import LTR390
from Luli_Ultrasonic import WaterLevelSensor
from Luli_pH import PHSensor
from Luli_OLED import OLEDMenuDisplay
from Luli_DHT import DHT22Handler
from Luli_Networkhandler import NetworkHandler
from Luli_MotorLEDControl import MotorAndLEDControl
import machine
import Luli_CONFIG
import utime

MOTOR_LED_CONTROL = MotorAndLEDControl()

# Sensor Initialization
PH_SENSOR = PHSensor()
UV_SENSOR = LTR390()
TANK_SENSOR = WaterLevelSensor()
DHTS = DHT22Handler()


# External Hardware/Misc Initialization
OLED = OLEDMenuDisplay()
NETWORK = NetworkHandler(Luli_CONFIG.WIFI_SSID, Luli_CONFIG.WIFI_PASSWORD, Luli_CONFIG.SERVER_URL)

def log_error(e):
    with open('error_log.txt', 'a') as file:  # 'a' opens the file for appending
        timestamp = utime.localtime()  # Get the current time
        readable_timestamp = "{year}/{month}/{day} {hours}:{minutes}:{seconds}".format(
            year=timestamp[0], month=timestamp[1], day=timestamp[2],
            hours=timestamp[3], minutes=timestamp[4], seconds=timestamp[5]
        )
        file.write('{} - Error: {}\n'.format(readable_timestamp, e))

def sensor_uv_read():
    # Give the sensor some time to start
    utime.sleep(Luli_CONFIG.DELAY_UV_STARTUP)
    raw, uv_intensity = UV_SENSOR.get_uv_data()
    print("RAW: {}".format(raw))
    print("UV Intensity: {}µW/cm²".format(uv_intensity))
    #return raw, uv_intensity
    return uv_intensity

def sensor_ph_read():
    ph_level = PH_SENSOR.get_ph()
    print("Current pH level:", ph_level)
    return ph_level

#def sensor_tank_calibrate():
#    TANK_SENSOR.calibrate_tank_full()
#    TANK_SENSOR.calibrate_tank_empty()

def sensor_tank_read():
    val = TANK_SENSOR.get_water_level()
    if val > 100:
        val = 100
    return val
    

def sensor_temp_read():
    # Compute average temp of sensors 0 to 3
    total_temp = 0
    for i in range(4):
        # Average and convert to Fahrenheit
        temp = DHTS.get_temperature(i)
        num_DHTs = 4
        if temp is not None:
            total_temp += ((temp * 9/5) + 32)
        else:
            total_temp += 0
            num_DHTs = num_DHTs - 1
    if num_DHTs <= 1:
        num_DHTs = 1
    avg_temp = total_temp / num_DHTs
    print("Average temperature:", avg_temp)
    return avg_temp

def sensor_humidity_read():
    # Compute average humidity of sensors 0 to 3
    total_hum = 0
    num_DHTs = 4
    for i in range(4):
        hum = DHTS.get_humidity(i)
        if hum is not None:
            total_hum += DHTS.get_humidity(i)
            
        else:
            total_hum += 0
            num_DHTs = num_DHTs - 1
    if num_DHTs <= 1:
        num_DHTs = 1
    avg_hum = total_hum / num_DHTs
    print("Average humidity:", avg_hum)
    return avg_hum

def update_display(plant_name='Basil', planted_date='4/29/24', harvest_date='5/20/24', ph_param=None, temp_param=None, light_param=None, humidity_param=None, tank_param=None):
    print("Updating display")
    ph = ph_param if ph_param is not None else sensor_ph_read()
    temp = temp_param if temp_param is not None else sensor_temp_read()
    light = light_param if light_param is not None else sensor_uv_read()
    humidity = humidity_param if humidity_param is not None else sensor_humidity_read()
    tank = tank_param if tank_param is not None else sensor_tank_read()

    OLED.print_sensor_data(ph=ph, temp=temp, light=light, humidity=humidity, tank=tank)
    utime.sleep(Luli_CONFIG.DELAY_OLED)
    OLED.print_plant_menu(plant_name=plant_name, planted_date=planted_date, harvest_date=harvest_date)
    utime.sleep(Luli_CONFIG.DELAY_OLED)

def send_all_data(ph_param=None, temp_param=None, light_param=None, humidity_param=None, tank_param=None):
    ph = ph_param if ph_param is not None else sensor_ph_read()
    temp = temp_param if temp_param is not None else sensor_temp_read()
    light = light_param if light_param is not None else sensor_uv_read()
    humidity = humidity_param if humidity_param is not None else sensor_humidity_read()
    tank = tank_param if tank_param is not None else sensor_tank_read()


    data = {
        "ph": ph,
        "temp": temp,
        "light": light,
        "humidity": humidity,
        "tank": tank
    }
    try:
        response = NETWORK.send_data(Luli_CONFIG.ENDPOINT_UPDATE_ALL_SENSOR_DATA, data)
    except Exception as e:
        print("Error sending all sensor data:", e)
        #log_error(e)
    return response

def send_data(data, data_label):
    response = None
    
    if data_label == 'ph':
        try:
            response = NETWORK.send_data(Luli_CONFIG.ENDPOINT_UPDATE_PH_DATA, data)
        except Exception as e:
            print("Error sending pH data:", e)
            #log_error(e)
    elif data_label == 'temp':
        try:
            response = NETWORK.send_data(Luli_CONFIG.ENDPOINT_UPDATE_TEMP_DATA, data)
        except Exception as e:
            print("Error sending temperature data:", e)
            #log_error(e)
    elif data_label == 'light':
        try:
            response = NETWORK.send_data(Luli_CONFIG.ENDPOINT_UPDATE_UV_DATA, data)
        except Exception as e:
            print("Error sending UV data:", e)
            #log_error(e)
    elif data_label == 'humidity':
        try:
            response = NETWORK.send_data(Luli_CONFIG.ENDPOINT_UPDATE_HUMIDITY_DATA, data)
        except Exception as e:
            print("Error sending humidity data:", e)
            #log_error(e)
    elif data_label == 'tank':
        try:
            response = NETWORK.send_data(Luli_CONFIG.ENDPOINT_UPDATE_TANK_DATA, data)
        except Exception as e:
            print("Error sending tank data:", e)
            #log_error(e)
    else:
        print("Invalid data label")

    # if response was successful, return True
    if response == None:
        return False
    if response.status_code == 200:
        print("Data sent!")
        return True
    else:
        return False
    

def override(next_manual_override_check_time):
    # Check for manual override every X seconds
    current_time = utime.time()
    if current_time >= next_manual_override_check_time:
        try:
            # Check for manual override
            #print('4')
            override_commands = NETWORK.get_manual_override()
            if override_commands:
                print("Manual override commands received:", override_commands)
                if 'motor' in override_commands:
                    if override_commands['motor'] == 'on':
                        MOTOR_LED_CONTROL.motor_on()
                    elif override_commands['motor'] == 'off':
                        MOTOR_LED_CONTROL.motor_off()
                if 'leds' in override_commands:
                    if override_commands['leds'] == 'on':
                        MOTOR_LED_CONTROL.leds_on()
                    elif override_commands['leds'] == 'off':
                        MOTOR_LED_CONTROL.leds_off()
        except Exception as e:
            print("Error getting manual override:", e)
            #log_error(e)
        
        # Update the next check time for manual overrides
        next_manual_override_check_time = current_time + Luli_CONFIG.MANUAL_OVERRIDE_CHECK_INTERVAL



if __name__ == '__main__':
    # Projects Day Demo Timings
    # 1. Read UV Sensor Data every 2 minutes
    # 2. Read pH Sensor Data and tank level data after every water pump cycle
    # 3. Read Temperature and Humidity every 30 seconds


    MOTOR_LED_CONTROL.motor_off()
    MOTOR_LED_CONTROL.leds_on()
    not_connected = True
    while not_connected:
        not_connected = NETWORK.connect_wifi()
    NETWORK.fetch_and_apply_settings()
    try:
        # Start time
        start_time = utime.time()
        next_uv_time = start_time + Luli_CONFIG.UV_READ_INTERVAL
        next_temp_humidity_time = start_time + Luli_CONFIG.TEMP_HUMIDITY_READ_INTERVAL
        next_motor_start_time = start_time # Start motor on startup
        next_motor_stop_time = start_time + Luli_CONFIG.DURATION_WATER_CYCLE
        next_manual_override_check_time = utime.time() + Luli_CONFIG.MANUAL_OVERRIDE_CHECK_INTERVAL  # Setting up the next time to check for manual overrides

        
        temperature = None
        humidity = None
        ph = None
        tank = None
        uv = None

        
        # Assumes tank is full on startup
        TANK_SENSOR.calibrate_tank_full()

        update_display()
        while True:

            current_time = utime.time()
            
            override(next_manual_override_check_time)
            # Start Water Cycle that reads pH and tank level
            if current_time >= next_motor_start_time:
                tank_level_percent = sensor_tank_read()  # Get the current water level percentage
                if tank_level_percent is not None and tank_level_percent > Luli_CONFIG.MINIMUM_WATER_LEVEL:
                    MOTOR_LED_CONTROL.motor_on()
                    next_motor_stop_time = current_time + Luli_CONFIG.DURATION_WATER_CYCLE  # Schedule to stop
                    next_motor_start_time = next_motor_stop_time + Luli_CONFIG.NEXT_WATER_CYCLE
                else:
                    print("Water level too low to start pump")
                    #next_motor_start_time = current_time + Luli_CONFIG.CHECK_WATER_LEVEL_INTERVAL  # Check again after some time
                    
            #print("CURRENT: ", current_time)
            #print("SToP TIME: ", next_motor_stop_time)
            override(next_manual_override_check_time)
            if current_time >= next_motor_stop_time:
                MOTOR_LED_CONTROL.motor_off()
                print("MOTOR SHOULD BE OFF")
                ph = sensor_ph_read()
                tank = sensor_tank_read()  # Read again after pump off in case level has changed
                update_display(ph_param=ph, tank_param=tank, plant_name="Basil", planted_date="4/29/24", harvest_date="5/20/24")
                #try:
                #    send_data(ph, 'ph')
                #    send_data(tank, 'tank')
                #except Exception as e:
                #    print("Error sending pH/tank data:", e)
                next_motor_start_time = current_time + Luli_CONFIG.NEXT_WATER_CYCLE  # Schedule next cycle

            override(next_manual_override_check_time)
            # Read UV and update display every 120 seconds
            if current_time >= next_uv_time:
                uv = sensor_uv_read()
                update_display(plant_name="Oregano", planted_date="4/29/24", harvest_date="5/27/24")
                #try:
                #    send_data(uv, 'light')
                #except Exception as e:
                    #print("Error sending UV data:", e)
                next_uv_time = current_time + Luli_CONFIG.UV_READ_INTERVAL  # Schedule next run

            override(next_manual_override_check_time)
            # Read Temperature and Humidity every 30 seconds
            if current_time >= next_temp_humidity_time:
                temperature = sensor_temp_read()
                humidity = sensor_humidity_read()
                update_display(plant_name="Tomatoes", planted_date="4/29/24", harvest_date="7/28/24")
                #try:
                #    send_data(temperature, 'temp')
                #    send_data(humidity, 'humidity')
                #except Exception as e:
                #    print("Error sending temp/humidity data:", e)
                next_temp_humidity_time = current_time + Luli_CONFIG.TEMP_HUMIDITY_READ_INTERVAL # Schedule next run

            override(next_manual_override_check_time)
            try:
                send_all_data(ph,temperature,uv,humidity,tank)
            except Exception as e:
                print("Error sending all data:", e)
            

            utime.sleep(0.1)  # Sleep for 100ms to reduce CPU usage

    except Exception as e:
        # SHUTDOWN ERROR CODE
        # Log the error
        log_error(e)
        print("Error:", e)
        MOTOR_LED_CONTROL.motor_off()
        for _ in range(3):
            MOTOR_LED_CONTROL.leds_off()
            utime.sleep(0.5)
            MOTOR_LED_CONTROL.leds_on()
            utime.sleep(0.5)
        MOTOR_LED_CONTROL.leds_off()
        #raise e
        #machine.reset() # Reset the board if an error occurs

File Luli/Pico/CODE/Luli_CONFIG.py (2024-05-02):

# Luli Hydroponics Config File
# This file will define all necessary pins and timing constants for the Luli Hydroponics system

#####################
#   PIN SETTINGS    #
#####################
PIN_UV_SENSOR_SDA = 0
PIN_UV_SENSOR_SCL = 1

PIN_OLED_SCK = 14
PIN_OLED_MOSI = 11 
PIN_OLED_CS = 13 # marked
PIN_OLED_RST = 10 
PIN_OLED_DC = 15 

PIN_ULTRASONIC_ECHO = 9
PIN_ULTRASONIC_TRIG = 17

PIN_DHT0 = 16
PIN_DHT1 = 18
PIN_DHT2 = 19
PIN_DHT3 = 20

PIN_MOTOR = 21
PIN_LED = 22
PIN_PH_SENSOR = 26




#########################
#   TIMING CONSTANTS    #
#########################
DELAY_OLED = 5 # seconds
DELAY_PH_RESPONSE = 50 # ms
DELAY_UV_STARTUP = 1 # seconds

TEMP_HUMIDITY_READ_INTERVAL = 30 # seconds
UV_READ_INTERVAL = 120 # seconds
MANUAL_OVERRIDE_CHECK_INTERVAL = 30 # seconds
#DURATION_WATER_CYCLE = 600 # seconds
DURATION_WATER_CYCLE = 60
NEXT_WATER_CYCLE = 3600 # seconds
DURATION_LED_CYCLE = 3600 # seconds



#########################
#   NETWORK SETTINGS    #
#########################
WIFI_SSID = 'Liam'
WIFI_PASSWORD = 'liampassword'
#WIFI_PASSWORD = None
SERVER_URL = 'https://lulihydroponics.ddns.net'



#########################
#   ENDPOINT SETTINGS   #
#########################
ENDPOINT_TEST = '/api/test'
ENDPOINT_GET_SETTINGS = '/api/get_settings'
ENDPOINT_SET_HARDWARE_ID = '/api/set_hardware_id'
ENDPOINT_UPDATE_SETTINGS = '/api/update_settings'
ENDPOINT_UPDATE_UV_DATA = '/api/update_uv_data'
ENDPOINT_UPDATE_PH_DATA = '/api/update_ph_data'
ENDPOINT_UPDATE_TEMP_DATA = '/api/update_temp_data'
ENDPOINT_UPDATE_HUMIDITY_DATA = '/api/update_humidity_data'
ENDPOINT_UPDATE_TANK_DATA = '/api/update_tank_data'
ENDPOINT_UPDATE_ALL_SENSOR_DATA = '/api/update_all_sensor_data'
ENDPOINT_MANUAL_OVERRIDE = '/api/get_manual_override'


######################
#   MISC CONSTANTS   #
######################
# https://optoelectronics.liteon.com/upload/download/DS86-2015-0004/LTR-390UV_Final_%20DS_V1%201.pdf
UVS_CONVERSION_FACTOR = 2300 # Conversion factor from the datasheet
VOLTAGE_AT_PH7 = 2.51
VOLTAGE_AT_PH4 = 3.03
MINIMUM_WATER_LEVEL = 20 # Minimum water level in the tank in percentage (%)
TANK_EMPTY_DISTANCE = 12 # Distance in cm when the tank is empty

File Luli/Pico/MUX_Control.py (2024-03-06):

from machine import Pin, I2C

# Set MUX select pins
selA = Pin(20, Pin.OUT)    # MUX Select A
selB = Pin(19, Pin.OUT)    # MUX Select B
selC = Pin(18, Pin.OUT)    # MUX Select C

muxData = Pin(15, Pin.IN)  # MUX Y Connection (Data Out)

####################
# UV I2C CONSTANTS #
####################
# Initialize I2C
# On the Raspberry Pi Pico, id=0 corresponds to GPIO 8 (SCL) and 9 (SDA)
UV_I2C = I2C(id=0, scl=Pin(1), sda=Pin(0), freq=400000)  # 400KHz SCL frequency

# UV Sensor constants
UVS_ADDRESS = 0x53          # UV Sensor I2C address
UVS_MAIN_CTRL = 0x00        # Main control register address
ALS_UVS_MEAS_RATE = 0x04    # Measurement rate register address
ALS_UVS_GAIN = 0x05         # Gain register address
UVS_DATA_0 = 0x10           # UV data LSB register address
UVS_DATA_1 = 0x11           # UV data middle byte register address
UVS_DATA_2 = 0x12           # UV data MSB register address

####################
# UV SENSOR CONFIG #
####################
# MAIN_CTRL - Enable UV sensor in UVS mode
UV_I2C.writeto_mem(UVS_ADDRESS, UVS_MAIN_CTRL, bytearray([0x02]))

# ALS_UVS_MEAS_RATE - Set measurement rate to 2000ms and resolution to 18 bits
# According to the datasheet, the measurement rate is the last 3 bits
# 0b00000011 corresponds to 2000ms
UV_I2C.writeto_mem(UVS_ADDRESS, ALS_UVS_MEAS_RATE, bytearray([0x03]))

# ALS_UVS_GAIN - Set gain to 3 (default according to datasheet)
# Gain value is in the last 3 bits, 0b00000001 corresponds to gain of 3
UV_I2C.writeto_mem(UVS_ADDRESS, ALS_UVS_GAIN, bytearray([0x01]))

################
# UV READ DATA #
################
def read_uv_data():
    # Read UV data bytes from the sensor
    uv_data_lsb = UV_I2C.readfrom_mem(UVS_ADDRESS, UVS_DATA_0, 1)[0]  # Least Significant Byte
    uv_data_mid = UV_I2C.readfrom_mem(UVS_ADDRESS, UVS_DATA_1, 1)[0]  # Middle Byte
    uv_data_msb = UV_I2C.readfrom_mem(UVS_ADDRESS, UVS_DATA_2, 1)[0]  # Most Significant Byte
    
    # Combine the three bytes to get the full UV data reading
    uv_data = (uv_data_msb << 16) | (uv_data_mid << 8) | uv_data_lsb
    return uv_data

# Poll the sensor and print the UV data
try:
    while True:
        uv_data = read_uv_data()
        print("UV Data reading:", uv_data)
except KeyboardInterrupt:
    print("Stopped polling UV data.")

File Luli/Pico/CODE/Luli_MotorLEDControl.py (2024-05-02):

from machine import Pin
import time
import Luli_CONFIG

class MotorAndLEDControl:
    def __init__(self, motor_pin=Luli_CONFIG.PIN_MOTOR, led_pin=Luli_CONFIG.PIN_LED):
        # Initialize motor and LED pins
        self.motor_gate = Pin(motor_pin, Pin.OUT)
        self.led_gate = Pin(led_pin, Pin.OUT)

    def motor_on(self):
        # Turn the motor on
        print("MOTOR ON")
        #self.motor_gate.value(1)

    def motor_off(self):
        # Turn the motor off
        print("MOTOR OFF")
        self.motor_gate.value(0)

    def leds_on(self):
        # Turn the LED on
        print("LEDS ON")
        self.led_gate.value(1)

    def leds_off(self):
        # Turn the LED off
        print("LEDS OFF")
        self.led_gate.value(0)

# Testing the class functionality
if __name__ == "__main__":
    control = MotorAndLEDControl()

    # Testing Motor Control
    control.motor_off()
    control.leds_off()
    time.sleep(3)
    control.leds_on()
    control.motor_on()
    time.sleep(360)
    control.motor_off()
    time.sleep(5)

    # Testing LED Control
    #while True:
    #    control.led_on()
    #    time.sleep(1)
    #    control.led_off()
    #    time.sleep(1)

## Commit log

2024-03-06 Added Pico code folder
2024-03-06 Added UV pico code
2024-04-11 pH sensor code added
2024-04-12 Added Pico LED control mosfet code
2024-04-14 Added motor control code
2024-04-15 Added motor and led combined test pico code
2024-04-15 Added sensor test data
2024-04-24 Combined Pico code
2024-04-26 Updated Pico Code
2024-04-26 Pico main code changes, config changes
2024-04-26 Pico code working as expected, debugging changes
2024-05-02 Added schematic and PCB files
    [LuliHydroponics copy.kicad_sch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]
